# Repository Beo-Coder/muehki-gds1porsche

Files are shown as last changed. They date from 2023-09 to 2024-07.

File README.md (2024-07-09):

# Porsche Mü(h)k

### Raspberry Pi Pico powered HID joystick for an old Porsche tractor

# Table of Contents
1. [Features](#features)
2. [Description](#description)
3. [Pinout](#pinout)
4. [Settings](#settings)
   1. [Load Preset](#load-preset)
   2. [Save Preset](#save-preset)
   3. [Modify Preset](#modify-preset)
      1. [General Settings](#general-settings)
      2. [Axes Settings](#axes-settings)
      3. [Button Settings](#button-settings)
  
   4. [Reinit Joystick](#reinit-joystick)
   5. [Reset Preset](#reset-preset)
   6. [Factory Reset](#factory-reset)
   7. [Disable Output](#disable-output)
5. [Notes](#notes)

# Features

- upto 8 analog axes
- upto 24 digital buttons
- fully customizable axes control curves
- fully customizable button behavior
- 10 different config presets
- easy control over rotary controller and LCD
- acts as gamepad or keyboard
- expandable 

# Description

Porsche Mü(h)k is a Raspberry Pi Pico powered controller
to emulate a HI-Device to control various games by using real actuators such as steering wheel,
gas and break pedal of a real tractor/car.
Various actuators can be connected either as analog or digital sensors, like potentiometers and buttons.
It can emulate a gamepad/joystick or a keyboard, depending on which mode is desired.
Each analog axis can operate in one of four different modes, giving full control over the behavior of the axis.

**It may be useful to use an emulator on the host PC to further configure the axes and buttons.**
# Usage

1. Connect all analog and digital actuators according to the pinout guide
2. Connect the Pico to a computer/laptop
3. Load/modify a preset
4. Have fun!

# Pinout
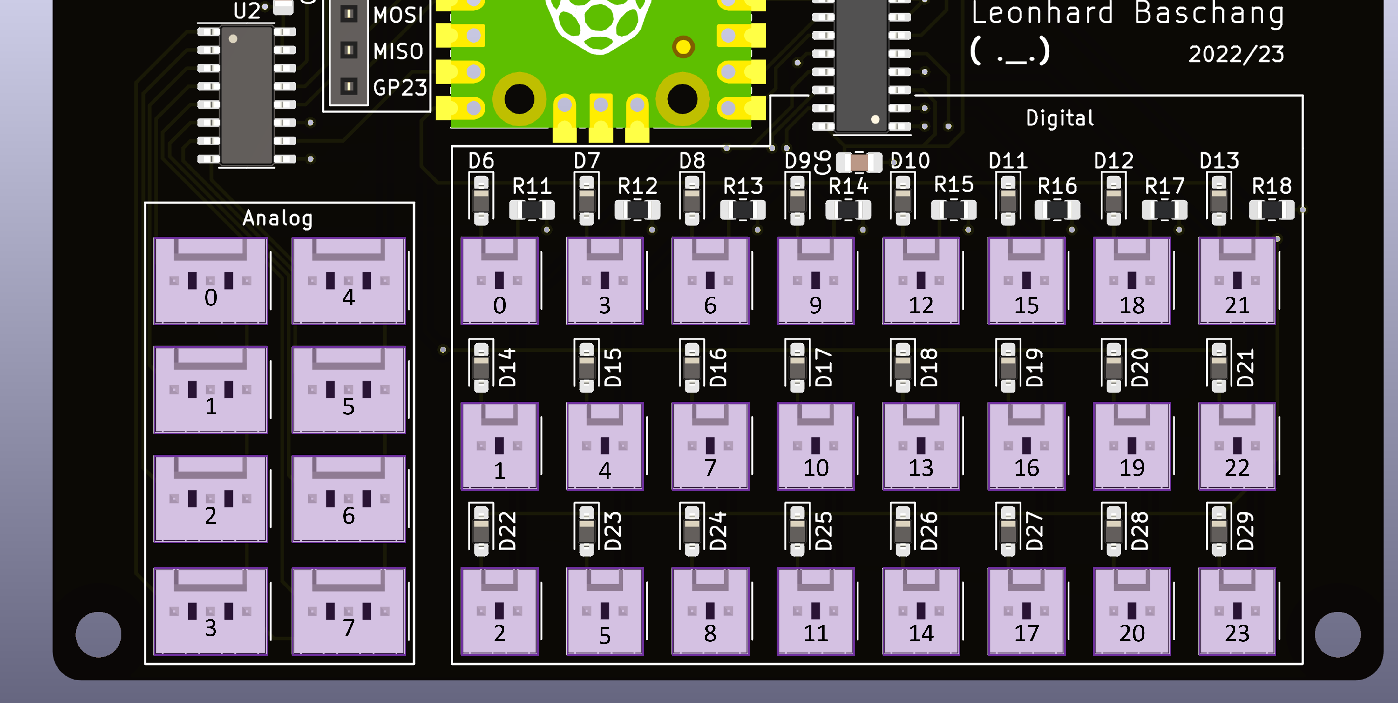
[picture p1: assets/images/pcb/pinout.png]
pinout


**Note**  
0 = Axis/Button 0 in software.  
If an axis/button is connected to port 2, but in software only two axes/buttons are selected,
the input is not sampled and has no output.

### Analog Headers

<pre> 
            +-----------+
+-----------+-----------+-----------+
|           |           |           |
|     A     |    GND    |    Vcc    |
|           |           |           |
+-----------+-----------+-----------+
</pre>

- A = Analog Input  
- GND = GND
- Vcc = Vcc (3.3V)  

### Digital Headers
<pre>
      +-----------+
+-----------+-----------+
|           |           |
|     S1    |    S2     |
|           |           |
+-----------+-----------+
</pre>

- S1 = Button contact 1
- S2 = Button contact 2

The Button must close or open these two connections.

**More detailed pinout in hardwareReadme**

# Settings

## Load Preset

1. Go to /Settings/Set Preset
2. Select desired preset
3. The Device will reset automatically

## Save Preset

1. Go to /Settings/Save Preset
2. Select desired preset
3. The config is saved to the preset

## Modify Preset

### General Settings
Menu: /Settings/General

- Number of Axes: Select the number of analog inputs/axes (0–8).
- Number of Buttons: Select the number of digital inputs/buttons (0–24).
- Digital Axis Mode: Set the mode for all axes
  - Analog: Axes will be emulated as analog axes (joystick)
  - Analog/Digital: Axes will be emulated as buttons on a joystick (only digital axes)
  - Keyboard: Axes and buttons will be emulated as a keyboard

On Analog/Digital and Keyboard mode, each axis will get two buttons/digital outputs assigned. 
One for an upper limit, one for a lower limit.
In these modes, an axis has only three states: center/off, upper limit, lower limit.

**Important:** After any change of these settings, you have to save the preset and restart the device! [Save Settings](#save-preset), [Reinit Joystick](#reinit-joystick)

### Axes Settings
Menu: /Settings/Axes/{*number of axis*}

- Calibrate: Calibrates the axis
- Base set: Sets the base of the control curve (only in exponential and logarithmic mode)
- Mode: Sets the mode of the axis (linear, exponential, logarithmic, digital)
- Digital Calibration: Calibration for digital mode

#### Calibration
It will calibrate your axis settings.  
Set the minimum position of the axis, this is the position where the output of the axis is the smallest.
Same with the maximum.  
If the center position is not calibrated, the center position is automatically set to the midpoint between minimum and maximum.
If the center is calibrated, one half of the calibration curve can be shorter/longer than the other.

#### Modes
- linear: The curve of the output is linear to the input
- exponential/logarithmic: The curve of the output is exponential/logarithmic to the input (based on base)
- digital: The axis has three states (center/off, upper limit, lower limit) in the general "Analog" mode these will be represented as an analog axis which is either 0, maximum or minimum.

#### Base set
In exponential and logarithmic mode, the base will set the curvature/steepness of the output curve.  
The output curve is split in two halves (base 0 and base 1).
Each base can be set separately, or both bases can be set to the same value.  
Base 0 is the base for the curve between minimum and the center, base 1 for the middle between maximum.  
For exponential curves the value should be greater than 0, for logarithmic curves the value should be smaller than 0.  
If the value is 0, it is linear.  
See also the diagrams below.

#### Digital Calibration
This will select the digital lower and upper limit of the axis.  
Set the position after which the lower/upper output/button should be pressed/set to minimum/maximum.  
All input values that are smaller/greater than the limit will result in the minimum/maximum output value.  
If the input value is between the boarder, no button is pressed (in (general) Analog/Digital or Keyboard mode) or the axis will be 0/center position ((general) Analog Mode).

#### Diagrams
The x-axis represents the input value.
- 0 = center (input) position
- -10 = minimum (input) position
- 10 = maximum (input) position

All of these values can be calibrated with axis calibration.

The y-axis represents the output value (analog mode only)
- 0 = center/0 output
- -10 = minimum (output) value
- 10 = maximum (output) value

Base 0 is the base for the curve between minimum and the center, base 1 for the middle between maximum.

These values will can't be directly controlled.

##### Linear curves:

| Linear axis curve without center calibration | Linear axis curve with (different) center calibration | Linear axis curve with (different) center calibration, different minimum calibration |
|---|---|---|
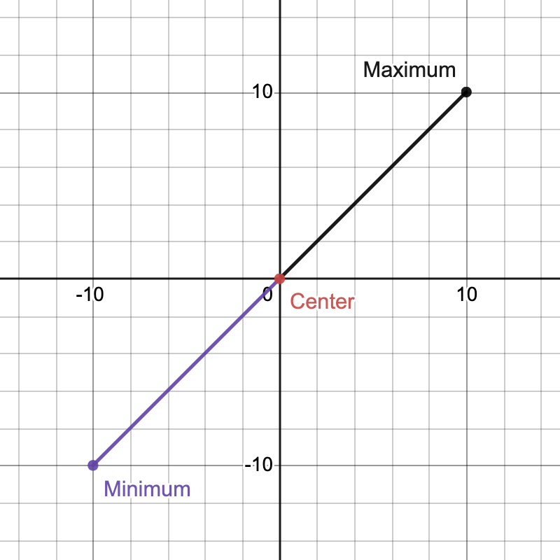
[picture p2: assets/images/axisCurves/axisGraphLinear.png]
linear diagram no center calibration linear axis control curve
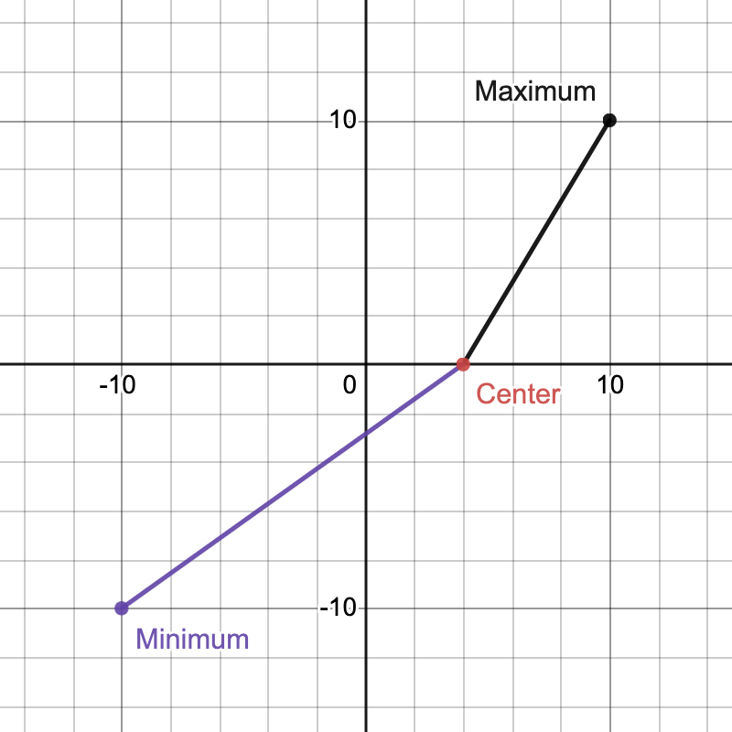
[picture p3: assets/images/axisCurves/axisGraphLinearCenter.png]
linear diagram center calibration linear axis control curve
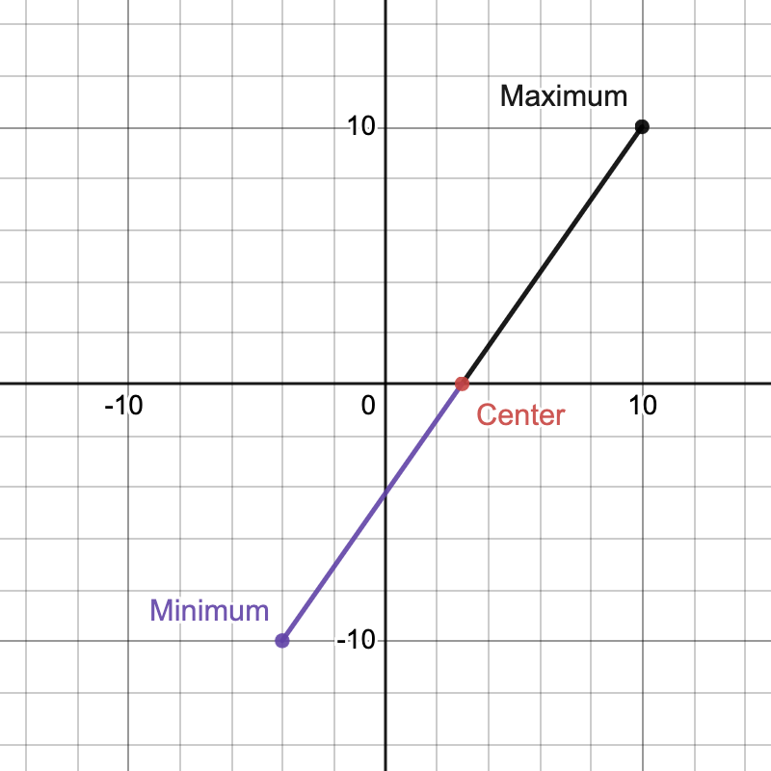
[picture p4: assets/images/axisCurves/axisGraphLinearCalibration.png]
linear diagram center calibration linear axis control curve
|  |  |  |

##### Exponential curves:
| Exponential axis curve without center calibration, same bases | Exponential axis curve without center calibration, different bases | Exponential axis curve with (different) center calibration, different bases |
|---|---|---|
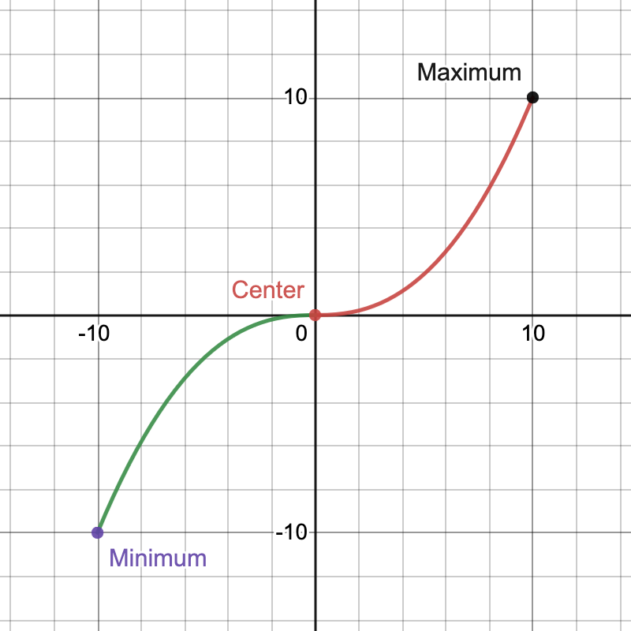
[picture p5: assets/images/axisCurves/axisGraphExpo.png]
expo diagram same bases no center calibration expo axis control curve
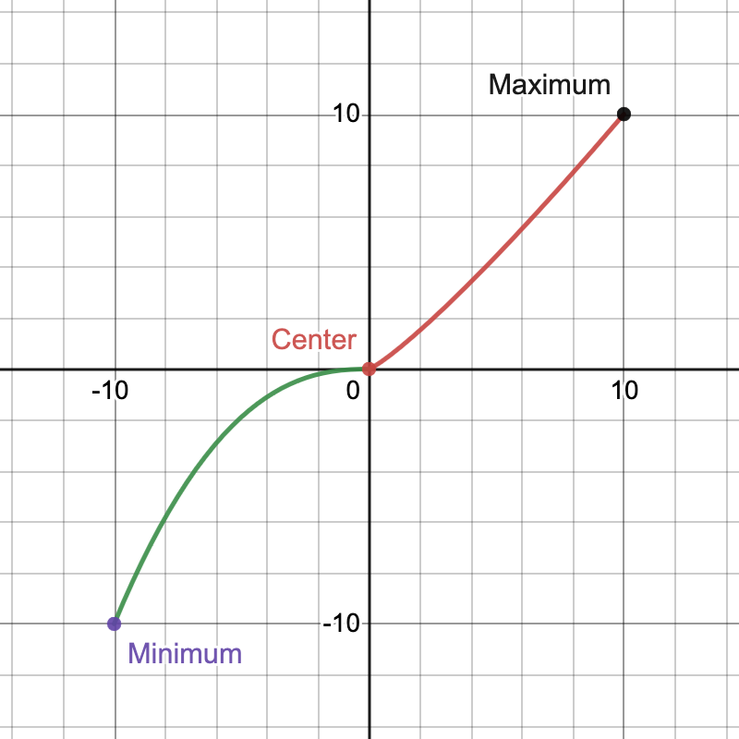
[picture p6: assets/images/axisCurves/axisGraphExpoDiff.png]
expo diagram diff base no center calibration expo axis control curve
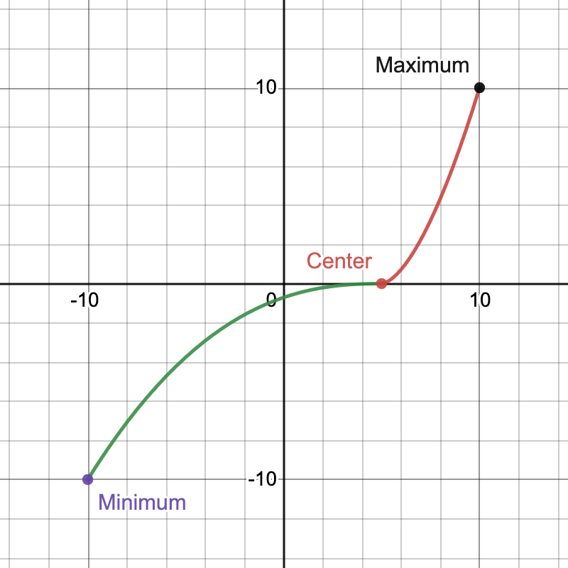
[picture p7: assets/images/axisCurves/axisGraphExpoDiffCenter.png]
expo diagram diff bases center calibration expo axis control curve
|  |  |  |

##### Logarithmic curves:
| Logarithmic axis curve without center calibration, same bases | Logarithmic axis curve without center calibration, different bases | Logarithmic axis curve with (different) center calibration, different bases |
|---|---|---|
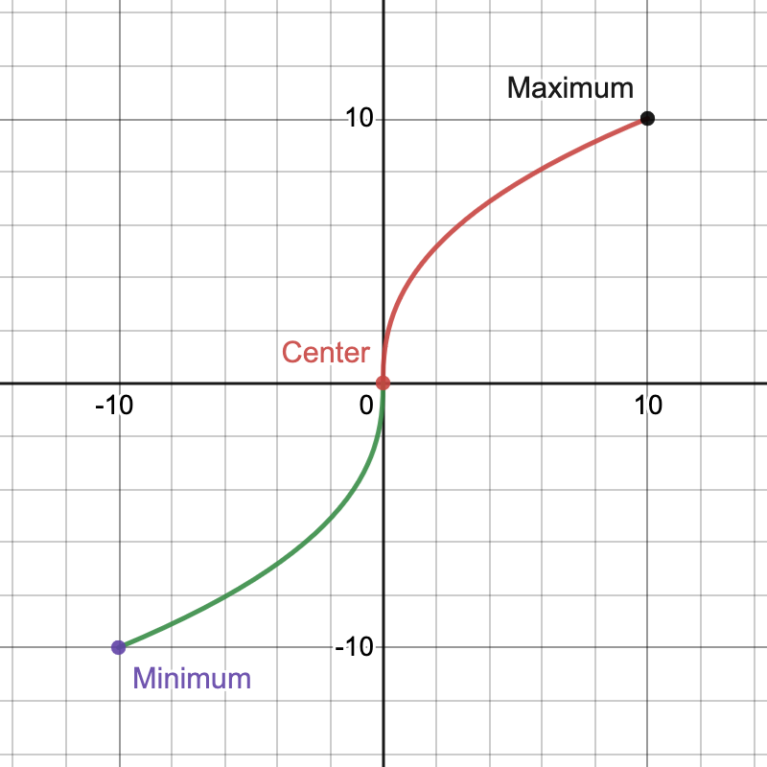
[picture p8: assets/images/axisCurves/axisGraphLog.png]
log diagram same bases no center calibration log axis control curve
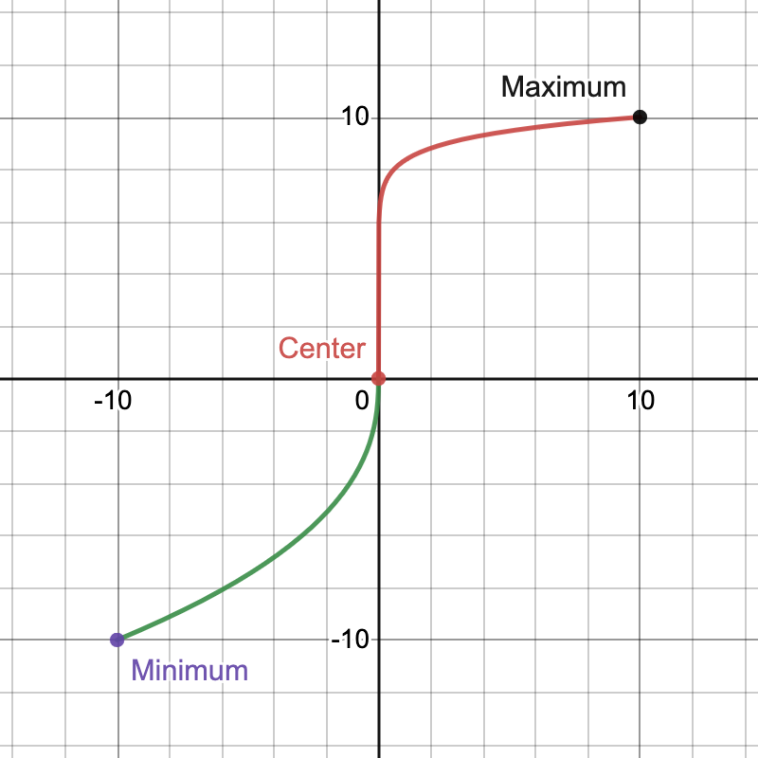
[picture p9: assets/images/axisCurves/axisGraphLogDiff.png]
log diagram diff base no center calibration log axis control curve
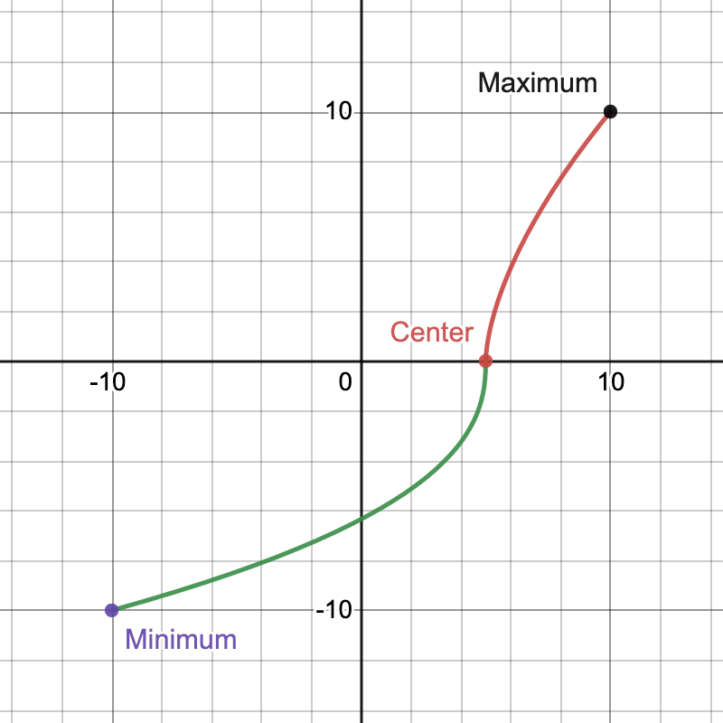
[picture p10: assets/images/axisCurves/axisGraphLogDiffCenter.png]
log diagram diff bases center calibration log axis control curve
|  |  |  |

##### Other curves (Combinations of all) :
| Exponential half with other half linear (without center calibration) | Exponential half with other half linear, (different) center calibration | Logarithmic half with other half exponential, (different) center calibration |
|---|---|---|
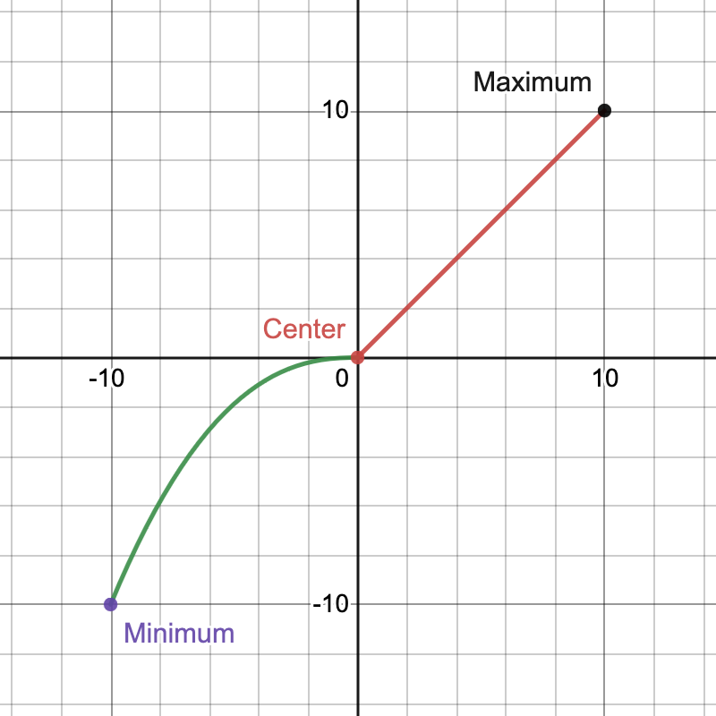
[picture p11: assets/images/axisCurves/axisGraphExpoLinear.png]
Exponential half with other half linear (without center calibration) other axis control curve
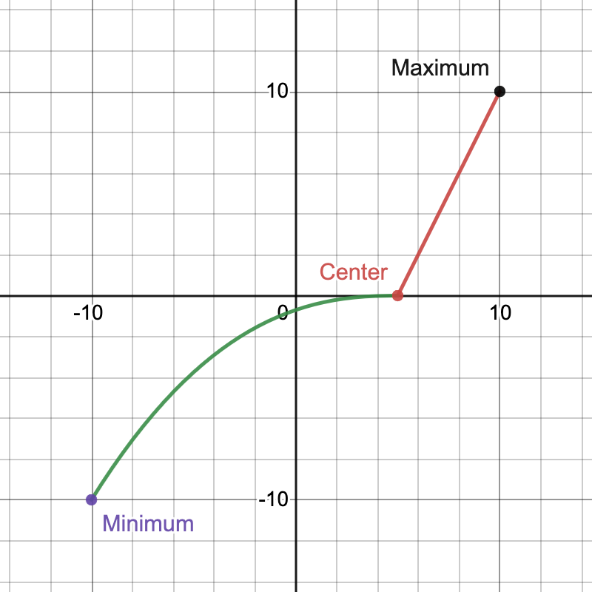
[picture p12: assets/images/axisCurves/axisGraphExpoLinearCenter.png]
Exponential half with other half linear, (different) center calibration other axis control curve
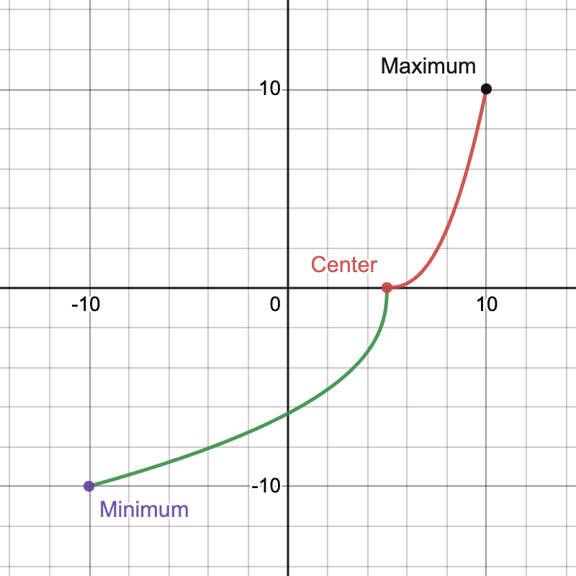
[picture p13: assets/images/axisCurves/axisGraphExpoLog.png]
Logarithmic half with Exponential other, (different) center calibration other axis control curve
|  |  |  |

**Note:**
There are many other ways to adjust the curves. See also the Desmos calculator: [Desmos calculator](https://www.desmos.com/calculator/y6jawpiyea)  
Note that the values of the Desmos calculator do not match those of the device.

### Button Settings

Menu: /Settings/Buttons/{*number of button*}

- Mode: Whether the button should behave as (temporary) button or as (toggle) button
- Type: Whether the button is NO (normally open) or NC (normally closed)

#### Mode
- Button: Button behaves as a button. There is only an output when the button is pressed.
- Toggle: Button behaves as a toggle button. Ont the first press the output goes high/1, the next press sets the output to 0/low.

#### Type
- Normally Open
- Normally Closed

Whether the button opens or closes on a press.

**Important:**
Axes and button settings are adapted immediately.
To keep them after the joystick is reloaded or turned off the settings must be saved. [Save Settings](#save-preset)  
There is no need to reinit the joystick after axes or button settings have changed.

## Reinit Joystick

This option reloads the joystick. 
All settings that are not saved will be lost.

## Reset Preset

The current selected preset will be set to factory settings.
After that, the joystick will be reloaded.

## Factory Reset

All settings (all presets) are set back to factory settings.
After that, the joystick will be reloaded.

## Disable Output
This setting disables the output of the computer.  
Especially useful in Keyboard mode.  
Press it again to enable the output again.

# Notes
The configuration/device can be tested on gamepad/joystick test websites/software.  
Example website I used for testing: [Gamepad tester](https://hardwaretester.com/gamepad)

More detailed hardware/software guides are under [READMEhardware](READMEhardware.md)/[READMEsoftware](READMEsoftware.md)  
There are also the board dimensions as well as the schematic/gerber files.

There are no settings stored on the Pico. So the Pico can also be used for other projects.

If there are any bugs/problems, or you have any questions, please contact me.

Mühk or Mük is are the same things. :)

( ._.)

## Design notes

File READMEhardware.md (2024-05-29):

# Porsche Mü(h)k Hardware

# Table of Contents
1. [Intro](#intro)
2. [Overview](#overview)
3. [Parts](#parts)
4. [Pinout](#pinout)
5. [Schematic](#schematic)
6. [Dimensions](#dimensions)

# Intro
This Readme file focuses on the hardware of Porsche Mü(h)k.

# Overview
The main part is the Raspberry Pi Pico MCU.
All the configuration data is stored on an external (64 Kb) EEPROM, so that the MCU can be exchanged and used for other projects.  
An 8-channel 12-bit ADC is used to interface up to eight analog sensors.  
An 8:1 analog multiplexer is used to further reduce the used pins of the Pico for up to 24 digital inputs.  
The board has connections for a rotary encoder (with button) and an I2C LCD.  
The board also has an area and connections to add an extra shield that can add various functions.  
All buses (SPI, I2C, UART) are routed out for easy debugging and/or add-ons/modifications.  
It has two LEDs for debug purposes.  
There is a 8x3 button matrix, with n-key rollover.
So each combination of buttons can be pressed and there is no ghosting.

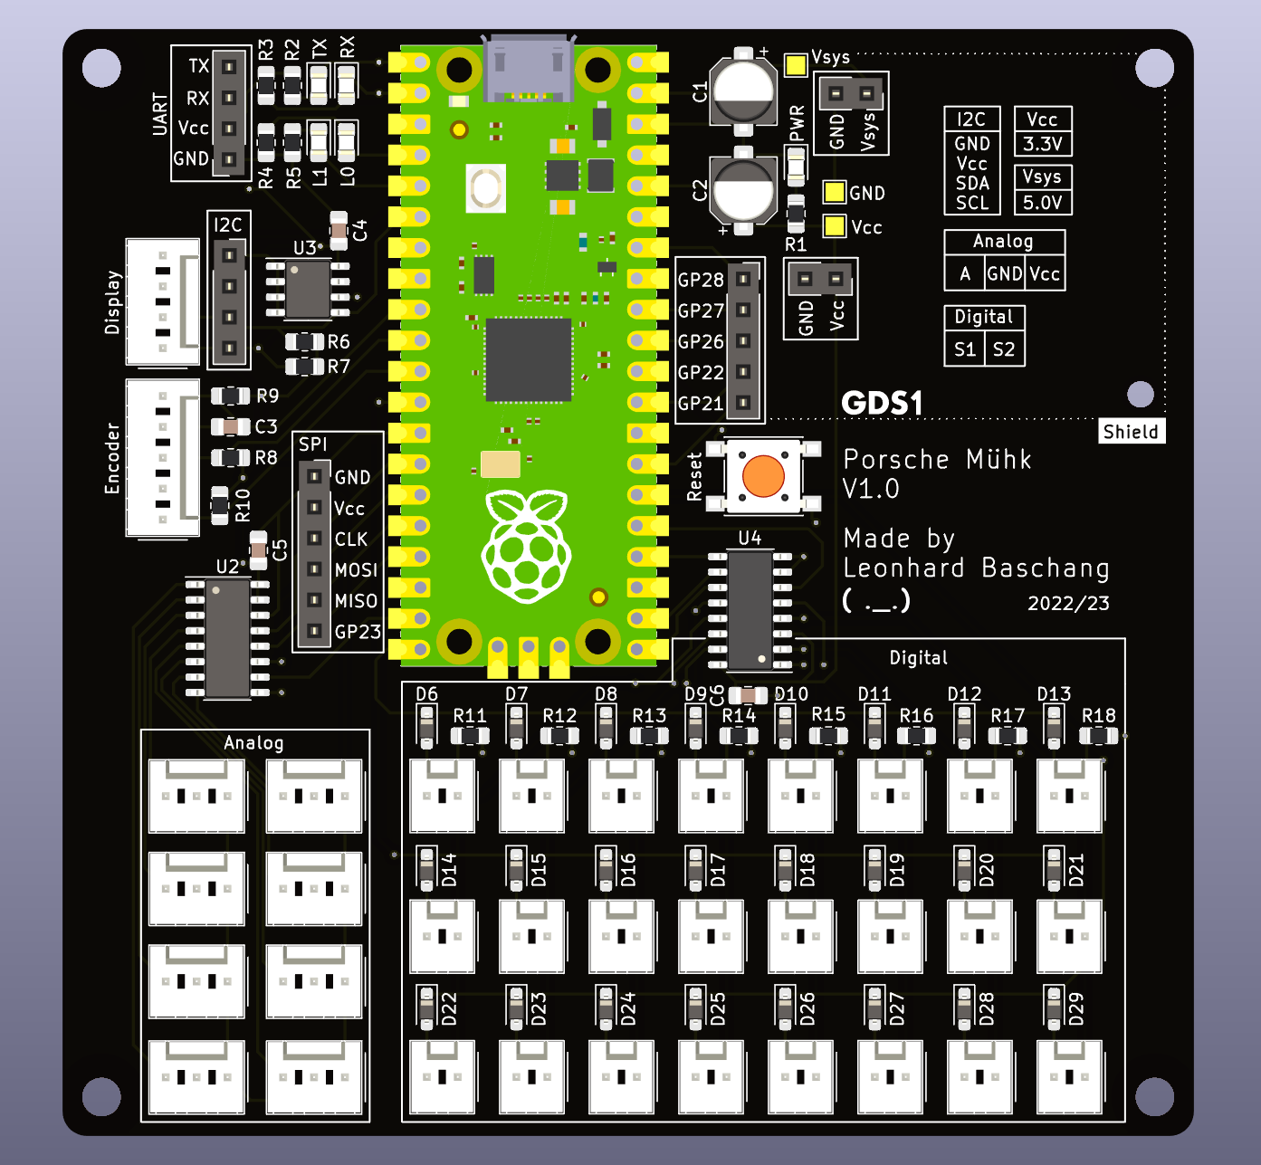
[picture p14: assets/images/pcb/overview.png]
overview


# Parts
- U1: Raspberry Pi Pico ([Raspberry Pi Pico](https://www.raspberrypi.com/products/raspberry-pi-pico/))
- U2: 8-Channel 12-Bit SPI ADC ([Microchip MCP3208](https://www.microchip.com/en-us/product/MCP3208))
- U3: 64 Kb I2C EEPROM ([Microchip 24LC64](https://www.microchip.com/en-us/product/24LC64))
- U4: 8:1 MUX ([Microchip CD74HC4051](https://www.ti.com/product/CD74HC4051))

- Display: Basic 20x4 I2C LC-Display (e.g. [LCD 20x4 AZ-Delivery](https://www.az-delivery.de/en/products/hd44780-2004-lcd-display-bundle-4x20-zeichen-mit-i2c-schnittstelle))
- Rotary Encode: Simple Rotary Encoder with button (e.g. [Rotary Encoder AZ-Delivery](https://www.az-delivery.de/en/products/drehimpulsgeber-modul))

- Connector housings for digital connections [PSK 254/2W](https://www.reichelt.de/kupplungs-leergehaeuse-crimptechnik-2-polig-psk-254-2w-p14857.html)
- Connector housings for analog connections [PSK 254/3W](https://www.reichelt.de/kupplungs-leergehaeuse-crimptechnik-3-polig-psk-254-3w-p14858.html)
- Connector housings for display connection [PSK 254/4W](https://www.reichelt.de/kupplungs-leergehaeuse-crimptechnik-4-polig-psk-254-4w-p694.html)
- Connector housings for encoder connection [PSK 254/5W](https://www.reichelt.de/kupplungs-leergehaeuse-crimptechnik-5-polig-psk-254-5w-p14859.html)
- Crimp contact for the housing [PSK-Contacts](https://www.reichelt.de/crimpkontakte-fuer-psk-254--20-stueck-psk-kontakte-p14861.html)

# Pinout

pinout

**Note**  
0 = Axis/Button 0 in software.  
If an axis/button is connected to port 2,
but in software only two axes/buttons are selected, the input is not sampled and no output.

### Analog Headers

<pre> 
            +-----------+
+-----------+-----------+-----------+
|           |           |           |
|     A     |    GND    |    Vcc    |
|           |           |           |
+-----------+-----------+-----------+
</pre>
- A = Analog Input
- GND = GND
- Vcc = Vcc (3.3V)

Analog input should not exceed Vcc (3.3V)

### Digital Headers
<pre>
      +-----------+
+-----------+-----------+
|           |           |
|     S1    |    S2     |
|           |           |
+-----------+-----------+
</pre>

- S1 = Button contact 1
- S2 = Button contact 2

The Button must close or open these two connections.

### Display Header
<pre> 
            +-----------------------+
+-----------+-----------+-----------+-----------+
|           |           |           |           |
|    GND    |    +5V    |    SDA    |    SCL    |
|           |           |           |           |
+-----------+-----------+-----------+-----------+
</pre>
- GND = GND
- +5V = +5V
- SDA = SDA (GPIO 4)
- SCL = SCL (GPIO 5)

SDA and SCL have a logic level of Vcc (3.3V)

### Encoder Header
<pre>
            +-----------------------------------+
+-----------+-----------+-----------+-----------+-----------+
|           |           |           |           |           |
|    CLK    |    GND    |    DT     |    GND    |    BT     |
|           |           |           |           |           |
+-----------+-----------+-----------+-----------+-----------+
</pre>
- CLK = CLK-Pin of Encoder
- GND = GND
- DT = DT-Pin of Encoder
- BT = Button pin of Encoder

CLK, DT and BT are pulled up to VCC. To get a signal, they need to be connected to GND.

**Note**  
During testing, I found a problem with presumably voltage spikes from the encoder when it is turned. 
To reduce them put a ceramic capacitor in parallel with a resistor in series with the CLK signal. 
This should be as close to the encoder as possible.
In a next version of the pcb, this maybe could be put on the pcb itself.
<pre>
                                 +------------+  
                           +-----+            +-----+
                           |     +------------+     |
                           |          100Ω          |
                           |                        |
CLK from Encoder +---------+                        +---------+ CLK to CLK Pin on Header
                           |                        |
                           |         |    |         |
                           |         |    |         |
                           +---------+    +---------+
                                     |    | 
                                     |    | 
                                      100nF
</pre>
### Notes
Note that all pins are only 3.3V tolerant.  
The various other connectors (SPI, I2C, UART, GPIO) are labeled on the silkscreen of the PCB.
CS of the ADC is on GPIO 14.  
LED 0 (L0) is connected to GPIO 2.  
LED 1 (L1) is connected to GPIO 3.

# Schematic
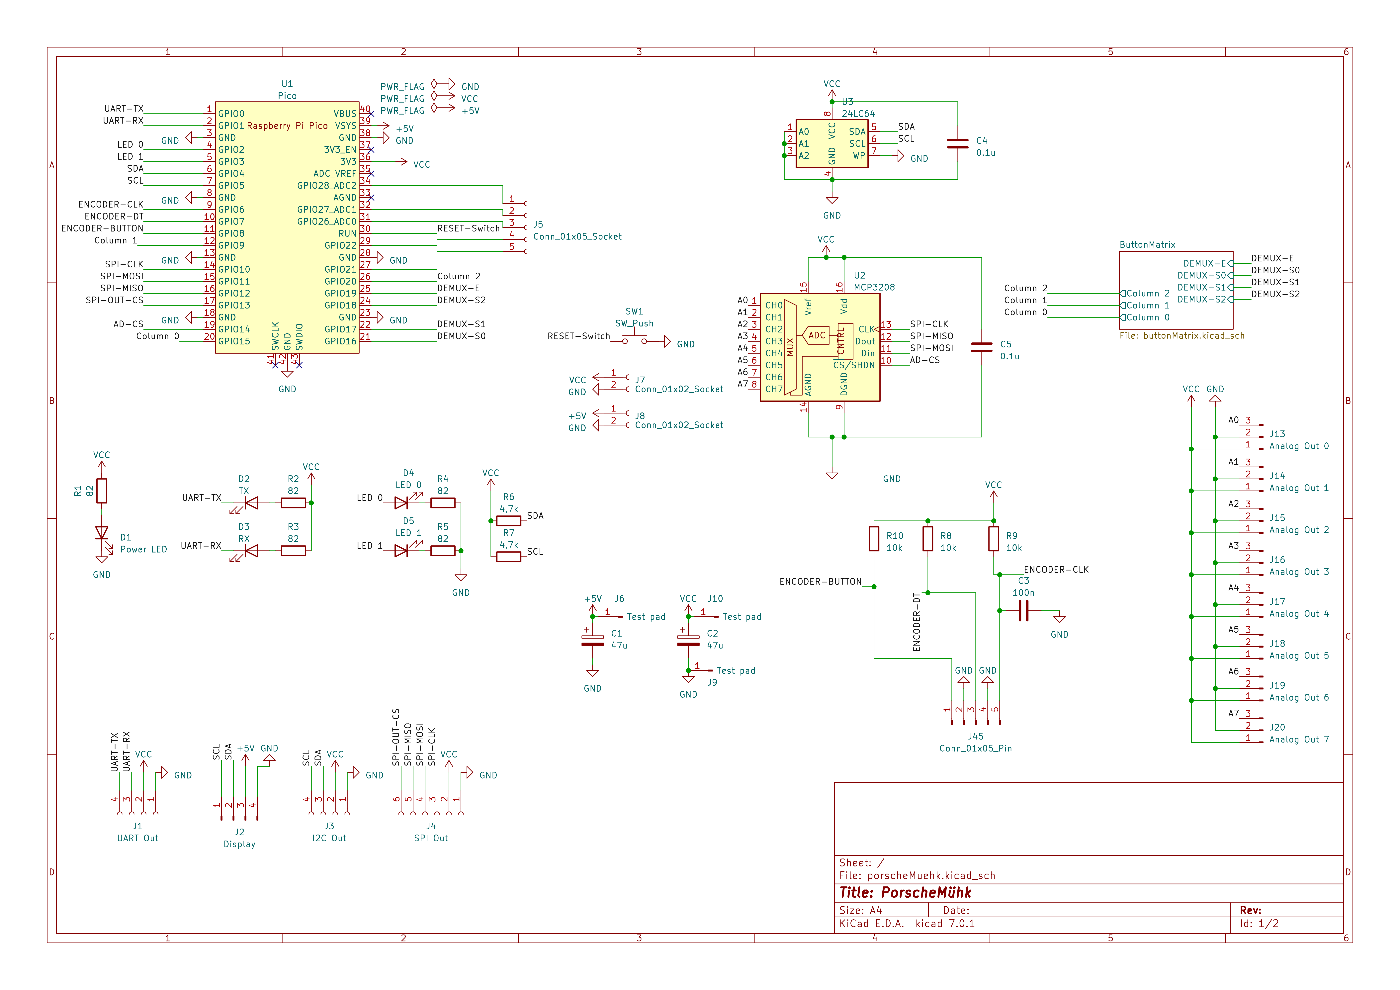
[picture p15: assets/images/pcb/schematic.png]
schematic


## Button matrix schematic
schematic button matrix

# Dimensions

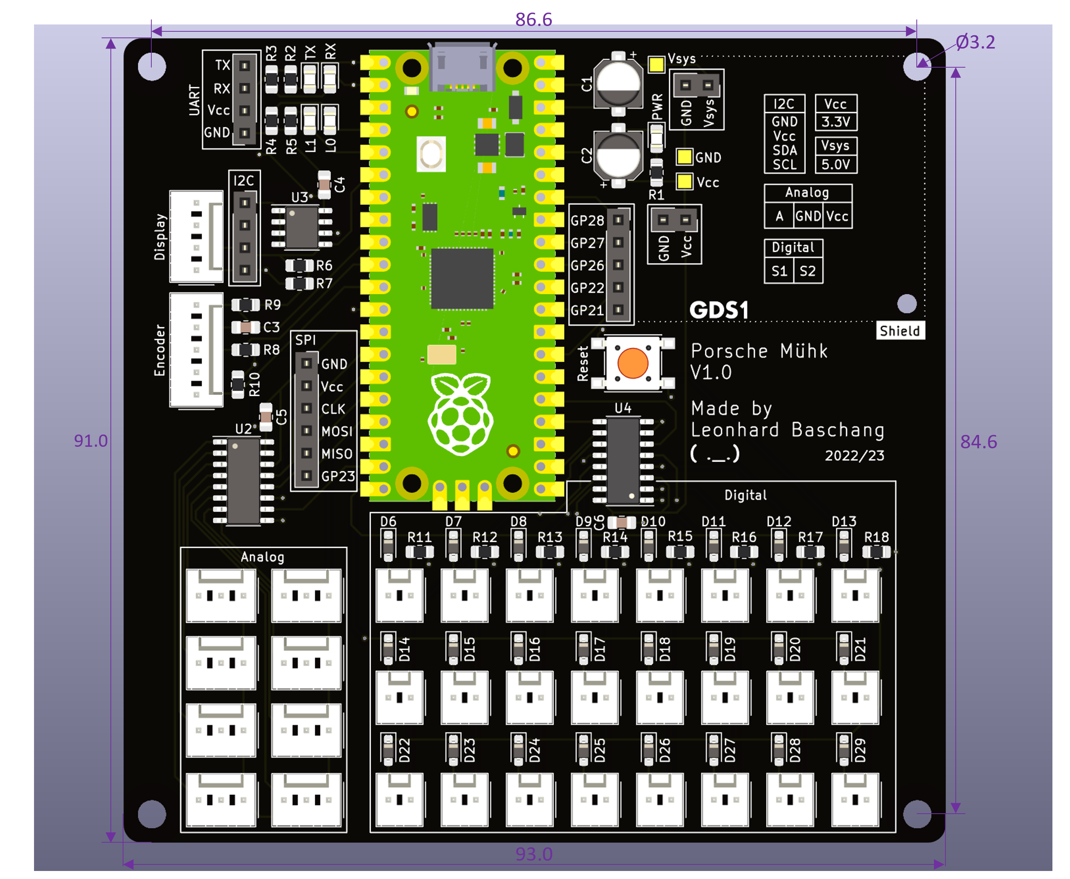
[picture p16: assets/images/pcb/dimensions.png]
dimensions


## Shield Dimensions

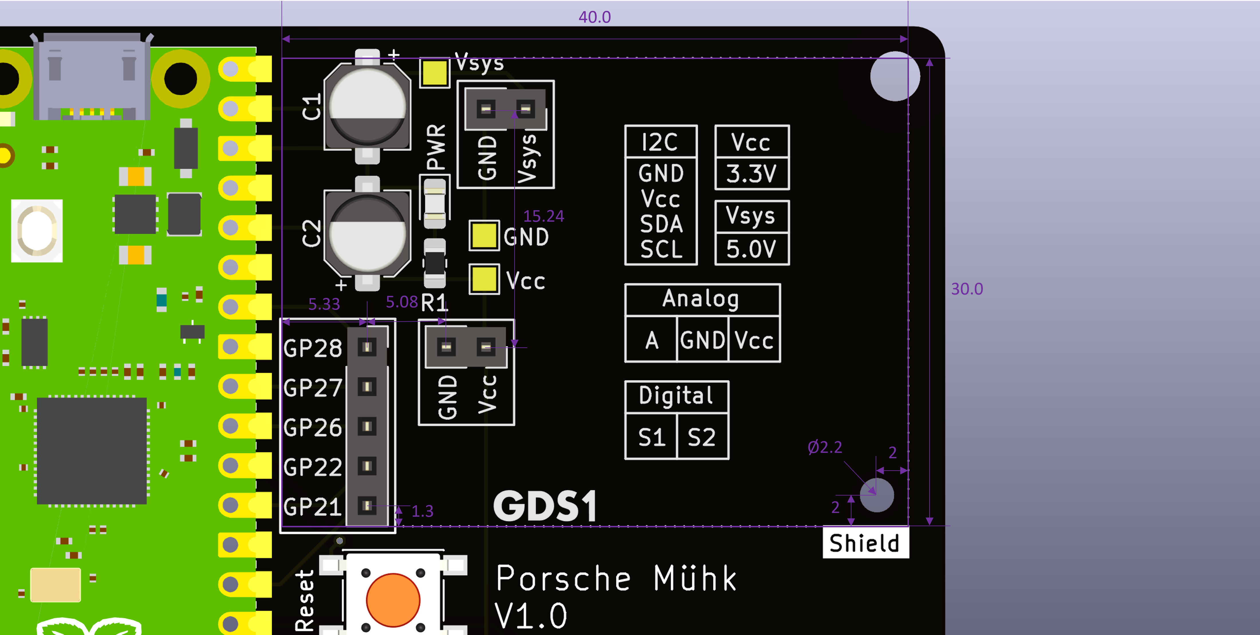
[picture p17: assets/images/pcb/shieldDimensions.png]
shield dimensions dimensions shield


## Notes
All the connectors for the shield are spaced with multiple of 2.54mm, so normal 2.54mm PCB can be used.  
All dimensions in mm.
KiCAD files and gerber files can be found [here](hardware)

( ._.)

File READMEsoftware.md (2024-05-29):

# Porsche Mü(h)k Software

# Table of Contents
1. [Intro](#intro)
2. [Overview](#overview)
3. [Emulating](#emulating-a-gamepadkeyboard)
4. [Memory Map](#eeprom-memory-map)

# Intro
This Readme file focuses on the software of Porsche Mü(h)k.

# Overview
This file will not explain all aspects of the software.
Only important principles are explained.  

The software is written in C/C++ with Platform IO.
It can also be imported in the Arduino IDE.

I know that the software can certainly be made better and cleaner.
Especially the whole menu LCD input.

# Emulating a Gamepad/Keyboard

In Analog and Analog/Digital mode the Pico will emulate a gamepad.

Each axis on the device will be one axis on the gamepad.
Each button on the device will be one button on the gamepad.  
In Analog/Digital mode for each axis, there are two extra buttons created.

To know which axis/button is which uses a gamepad tester.
Example website I used for testing: [Gamepad tester](https://hardwaretester.com/gamepad)

For the Keyboard mode, each button has one key and each axis has two keys.  
The emulated Keyboard is an n-key rollover keyboard.  
To know which axis/button is which use a keyboard tester.
Example website I used for testing: [Keyboard tester](https://keyboard-test.space/)

The libraries used for emulating were written by me  
[Gamepad library](https://github.com/Beo-Coder/muehk-lib-JoystickHID)  
[Keyboard library]() - Coming soon (or never... (Just see the code if you need it))

# EEPROM Memory Map

All configuration data is stored on the external EEPROM chip.
The EEPROM I used has an address range from 0x0000 to 0x1FFF so 8191 bytes in total.

The EEPROM is divided into two different sections. 
A general section and the sections for all presets.

The general section is 20 bytes wide and stores the following:
- current preset
- 19 unused bytes

General section memory map:
<pre>
0x0000:  +-----------------------------------+
         | Current preset                    |
0x0001:  +-----------------------------------+
         | not used                          |
         .                                   .
         .                                   .
         |                                   |    
0x0014:  +-----------------------------------+
         |                                   |
         .                                   .
</pre>

The preset section contains all presets.
A preset is 405 bytes wide. So the reset of the EEPROM could theoretically store up to 20 presets.  

A preset contains the following data:
- 32 bytes per axis (2 bytes per calibration data, 2 bytes per digital calibration, 8 bytes per base, 1 byte for the mode, 1 byte for 8 single bit data, 4 bytes not used)
- 2 bytes per button (1 byte for 8 single bit data, 1 byte not used)
- 5 bytes for a general section (1 byte for axis count, 1 byte for button count, 1 byte for the joystick mode, 2 bytes not used)

In total, a 405 byte wide preset can hold 10 axes and 40 buttons.  
With the unused bytes, there is enough space to update/modify smaller things without doing a whole new memory map.  
Because the software normally only stores 10 presets, 4121 bytes are free.
These bytes could be used to store more presets or for any other thing that need to be stored.

Preset memory map:

<pre>
0x0014:  +-----------------------------------+  Preset 0 General Section (5 bytes)
         | Axis count                        |
0x0015:  +-----------------------------------+
         | Button count                      |
0x0016:  +-----------------------------------+
         | Mode                              |
0x0017:  +-----------------------------------+
         | Not used                          |
         |                                   |
0x0019:  +-----------------------------------+  Axis 0 (32 bytes)
         | calibration data 0 MSB            |
0x001A:  +-----------------------------------+
         | calibration data 0 LSB            |
0x001B:  +-----------------------------------+
         | calibration data 1 MSB            |
0x001C:  +-----------------------------------+
         | calibration data 1 LSB            |
0x001D:  +-----------------------------------+
         | calibration data 2 MSB            |
0x001E:  +-----------------------------------+
         | calibration data 2 LSB            |
0x001F:  +-----------------------------------+
         | digital calibration data 0 MSB    |
0x0020:  +-----------------------------------+
         | digital calibration data 0 LSB    |
0x0021:  +-----------------------------------+
         | digital calibration data 1 MSB    |
0x0022:  +-----------------------------------+
         | digital calibration data 1 LSB    |
0x0023:  +-----------------------------------+
         | base 0                            |
         |                                   |
         |                                   |
         |                                   |
         |                                   |
         |                                   |
         |                                   |
         |                                   |
0x002B:  +-----------------------------------+
         | base 1                            |
         |                                   |
         |                                   |
         |                                   |
         |                                   |
         |                                   |
         |                                   |
         |                                   |
0x0033:  +-----------------------------------+
         | mode                              |
0x0034:  +-----------------------------------+
         | bit data                          |
0x0035:  +-----------------------------------+
         | Not used                          |
         |                                   |
         |                                   |
         |                                   |
0x0039:  +-----------------------------------+  Axis 1-9 (32*9 bytes)
         |                                   |
         .                                   .

         .                                   .
         |                                   |
0x0159:  +-----------------------------------+  Button 0 (2 bytes)
         | single bit data                   |
0x015A:  +-----------------------------------+ 
         | not used                          |
0x015B:  +-----------------------------------+  Button 1-39 (2*39 bytes)
         |                                   |
         .                                   .

         .                                   .
         |                                   |
0x01a9:  +-----------------------------------+  Preset 1 General Section ...
         |                                   |
         .                                   .
         .                                   .
</pre>

To read/write to the EEPROM, I used my own library  
[EEPROM 24 lib](https://github.com/Beo-Coder/muehk-lib-Microchip-EEPROM-24)

( ._.)

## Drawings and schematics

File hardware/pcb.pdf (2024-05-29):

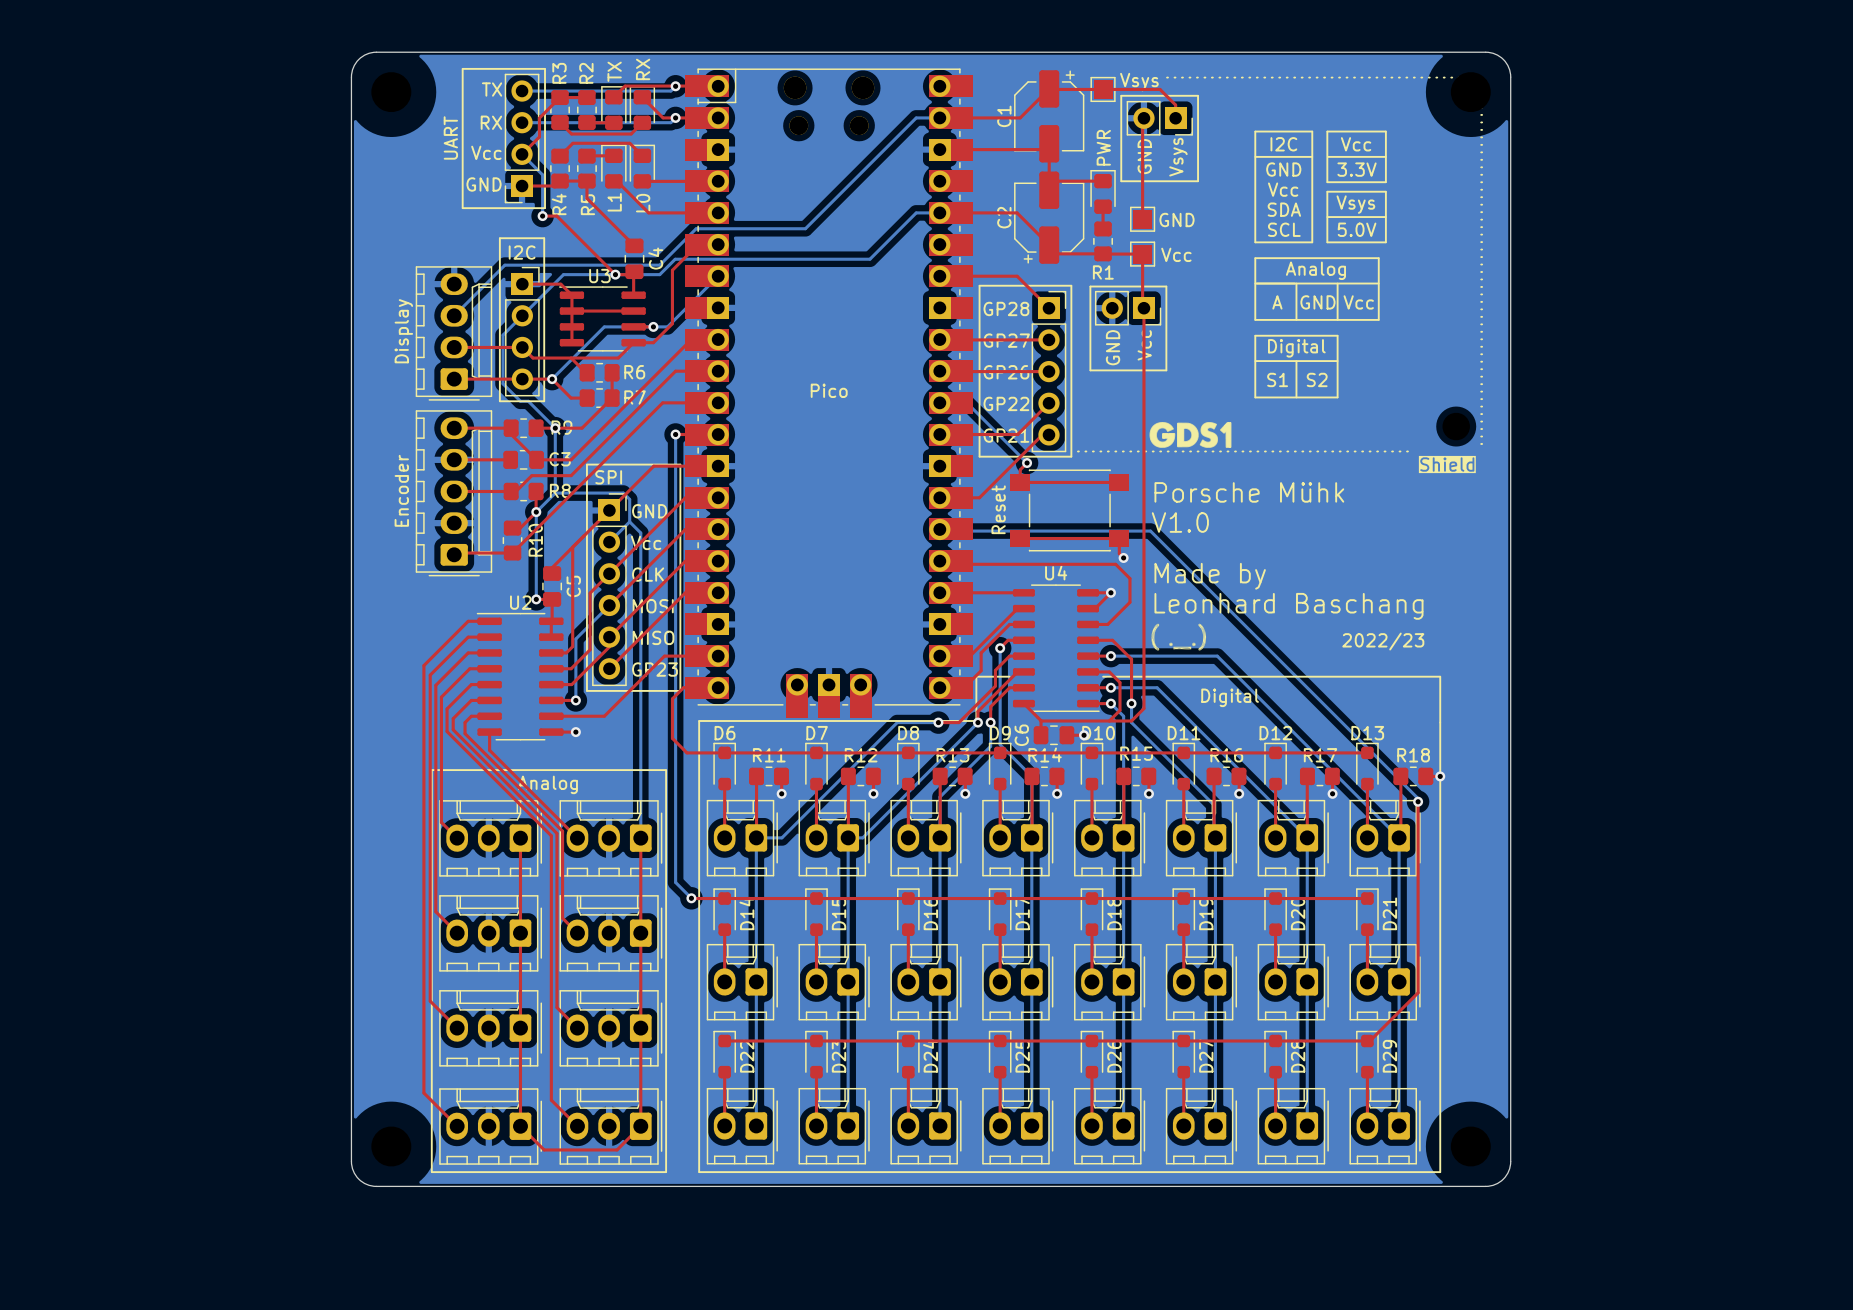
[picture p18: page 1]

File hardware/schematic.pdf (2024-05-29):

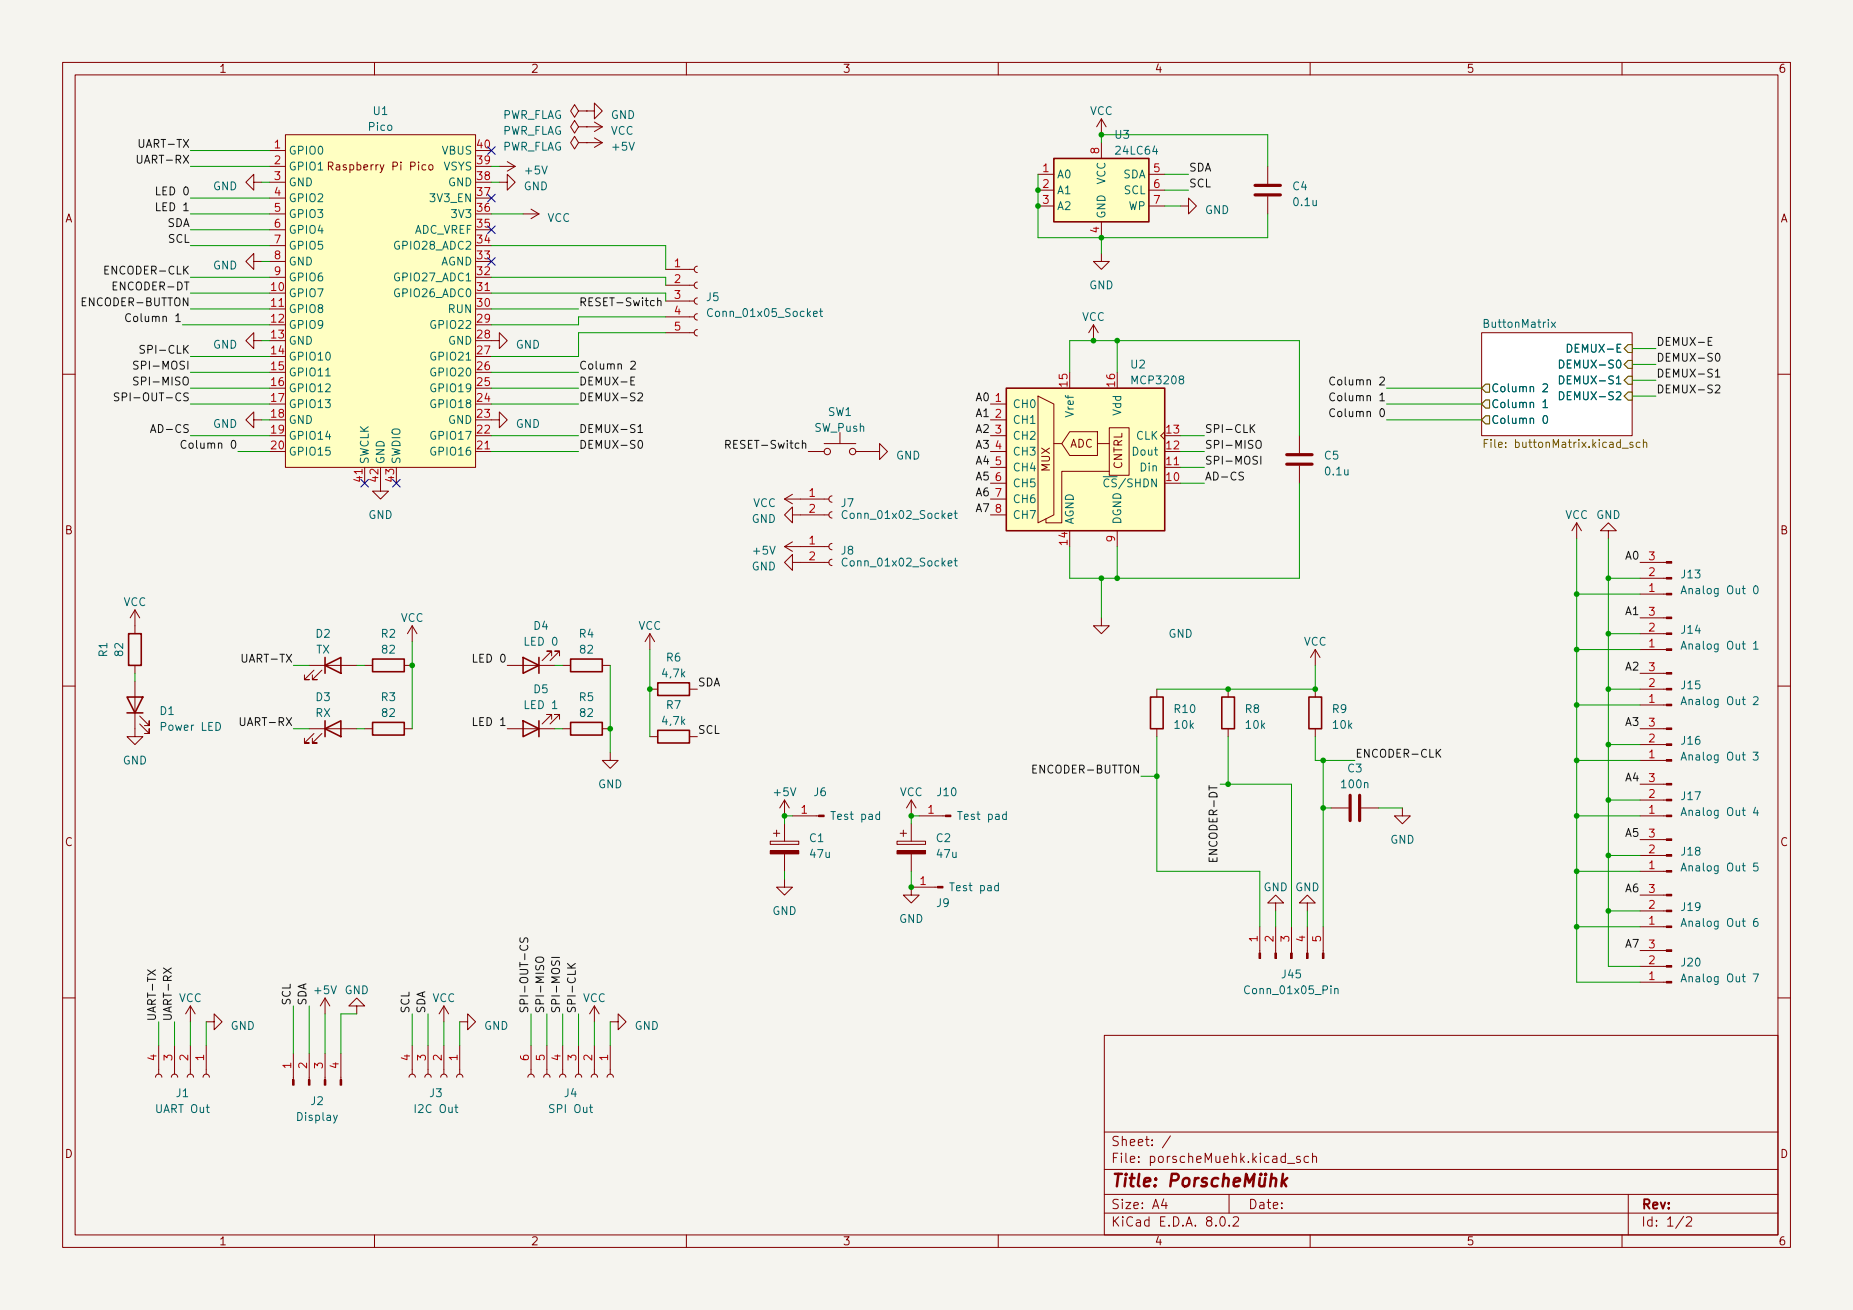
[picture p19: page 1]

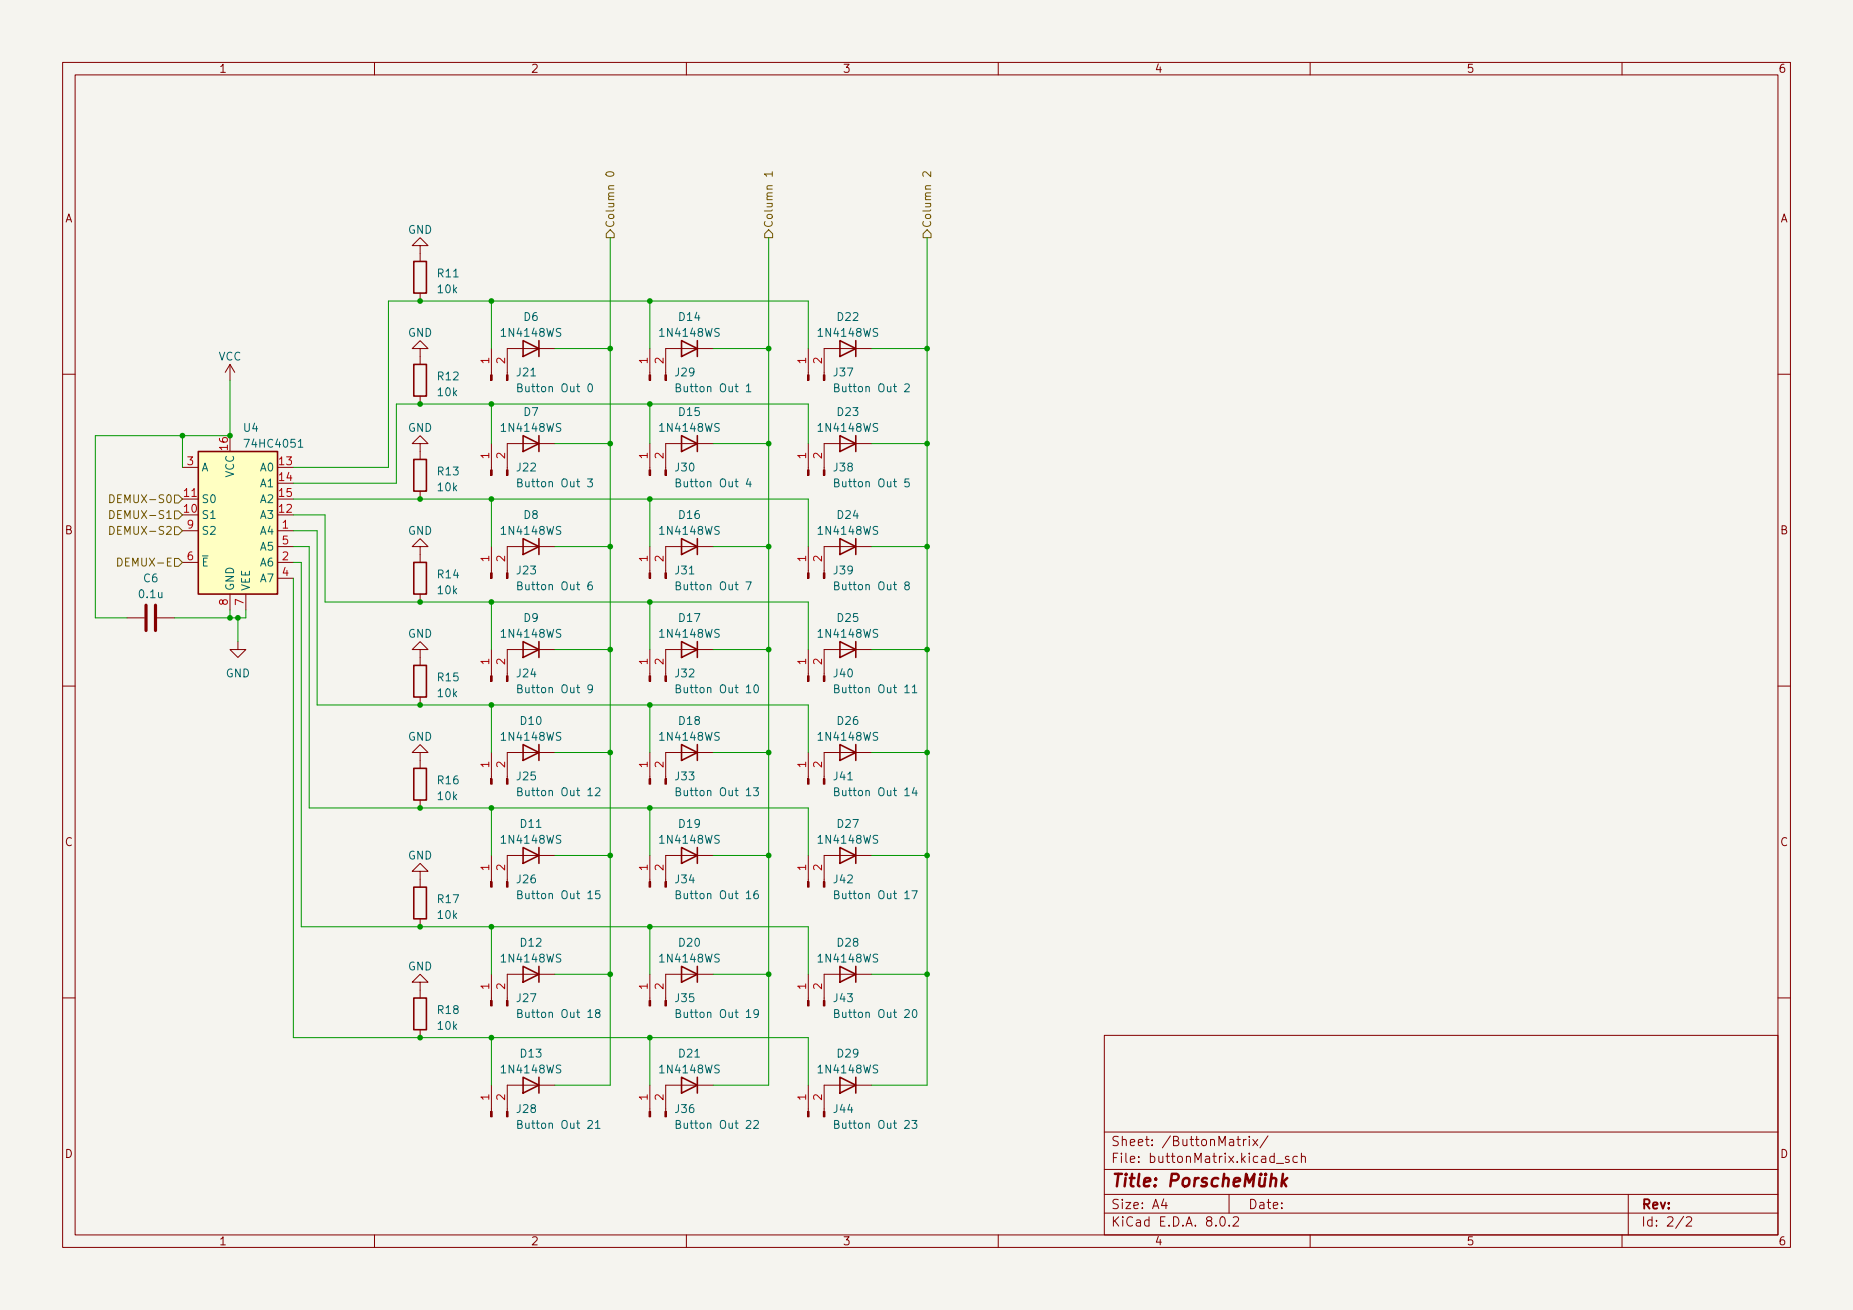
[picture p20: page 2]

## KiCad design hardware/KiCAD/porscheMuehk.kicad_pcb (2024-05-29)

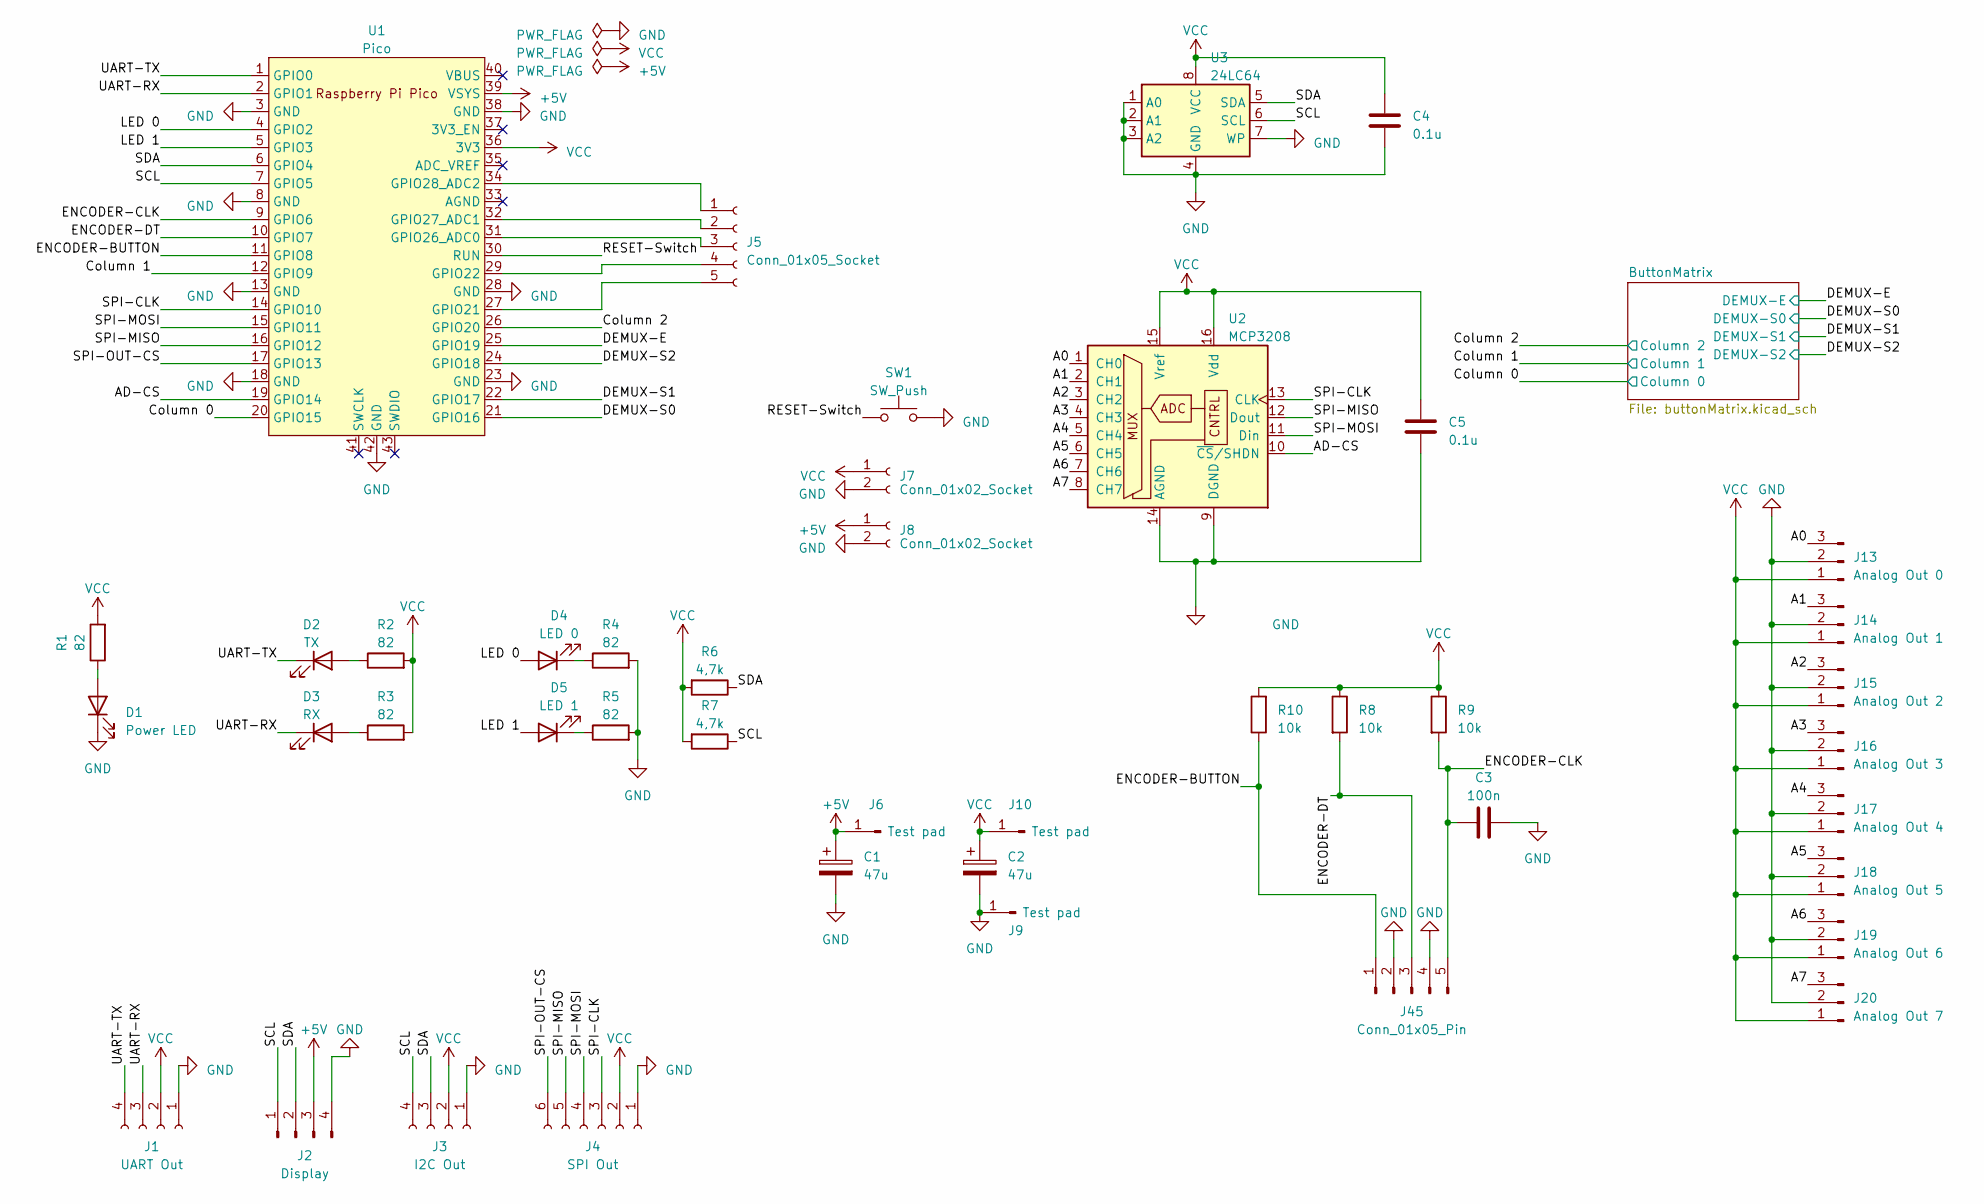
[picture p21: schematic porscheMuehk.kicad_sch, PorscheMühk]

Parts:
C1, C2: 47u; CP_Elec_5x5.3
C3: 100n; C_0805_2012Metric_Pad1.18x1.45mm_HandSolder
C4, C5: 0.1u; C_0805_2012Metric_Pad1.18x1.45mm_HandSolder
D1: Power LED; LED_0805_2012Metric_Pad1.15x1.40mm_HandSolder
D2: TX; LED_0805_2012Metric_Pad1.15x1.40mm_HandSolder
D3: RX; LED_0805_2012Metric_Pad1.15x1.40mm_HandSolder
D4: LED 0; LED_0805_2012Metric_Pad1.15x1.40mm_HandSolder
D5: LED 1; LED_0805_2012Metric_Pad1.15x1.40mm_HandSolder
J1: UART Out; PinSocket_1x04_P2.54mm_Vertical
J2: Display; Molex_KK-254_AE-6410-04A_1x04_P2.54mm_Vertical
J3: I2C Out; PinSocket_1x04_P2.54mm_Vertical
J4: SPI Out; PinSocket_1x06_P2.54mm_Vertical
J5: Conn_01x05_Socket; PinSocket_1x05_P2.54mm_Vertical
J6, J9, J10: Test pad; TestPoint_Pad_1.5x1.5mm
J7, J8: Conn_01x02_Socket; PinSocket_1x02_P2.54mm_Vertical
J13: Analog Out 0; Molex_KK-254_AE-6410-03A_1x03_P2.54mm_Vertical
J14: Analog Out 1; Molex_KK-254_AE-6410-03A_1x03_P2.54mm_Vertical
J15: Analog Out 2; Molex_KK-254_AE-6410-03A_1x03_P2.54mm_Vertical
J16: Analog Out 3; Molex_KK-254_AE-6410-03A_1x03_P2.54mm_Vertical
J17: Analog Out 4; Molex_KK-254_AE-6410-03A_1x03_P2.54mm_Vertical
J18: Analog Out 5; Molex_KK-254_AE-6410-03A_1x03_P2.54mm_Vertical
J19: Analog Out 6; Molex_KK-254_AE-6410-03A_1x03_P2.54mm_Vertical
J20: Analog Out 7; Molex_KK-254_AE-6410-03A_1x03_P2.54mm_Vertical
J45: Conn_01x05_Pin; Molex_KK-254_AE-6410-05A_1x05_P2.54mm_Vertical
R1, R2, R3, R4, R5: 82; R_0805_2012Metric_Pad1.20x1.40mm_HandSolder
R6, R7: 4,7k; R_0805_2012Metric_Pad1.20x1.40mm_HandSolder
R8, R9, R10: 10k; R_0805_2012Metric_Pad1.20x1.40mm_HandSolder
SW1: SW_Push; SW_Push_1P1T_NO_6x6mm_H9.5mm
U1: Pico; RPi_Pico_SMD_TH
U2: MCP3208; SOIC-16_3.9x9.9mm_P1.27mm
U3: 24LC64; SOIC-8_3.9x4.9mm_P1.27mm

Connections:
+5V: C1.1, J2.3, J6.1, J8.1, U1.39 (VSYS)
/A0: J13.3, U2.1 (CH0)
/A1: J14.3, U2.2 (CH1)
/A2: J15.3, U2.3 (CH2)
/A3: J16.3, U2.4 (CH3)
/A4: J17.3, U2.5 (CH4)
/A5: J18.3, U2.6 (CH5)
/A6: J19.3, U2.7 (CH6)
/A7: J20.3, U2.8 (CH7)
/AD-CS: U1.19 (GPIO14), U2.10 (~CS/SHDN)
/Column 0: U1.20 (GPIO15); also elsewhere on the board
/Column 1: U1.12 (GPIO9); also elsewhere on the board
/Column 2: U1.26 (GPIO20); also elsewhere on the board
/DEMUX-E: U1.25 (GPIO19); also elsewhere on the board
/DEMUX-S0: U1.21 (GPIO16); also elsewhere on the board
/DEMUX-S1: U1.22 (GPIO17); also elsewhere on the board
/DEMUX-S2: U1.24 (GPIO18); also elsewhere on the board
/ENCODER-BUTTON: J45.1, R10.1, U1.11 (GPIO8)
/ENCODER-DT: J45.3, R8.2, U1.10 (GPIO7)
/LED 0: D4.2 (A), U1.4 (GPIO2)
/LED 1: D5.2 (A), U1.5 (GPIO3)
/RESET-Switch: SW1.1, U1.30 (RUN)
/SCL: J2.1, J3.4, R7.1, U1.7 (GPIO5), U3.6 (SCL)
/SDA: J2.2, J3.3, R6.1, U1.6 (GPIO4), U3.5 (SDA)
/SPI-CLK: J4.3, U1.14 (GPIO10), U2.13 (CLK)
/SPI-MISO: J4.5, U1.16 (GPIO12), U2.12 (Dout)
/SPI-MOSI: J4.4, U1.15 (GPIO11), U2.11 (Din)
/SPI-OUT-CS: J4.6, U1.17 (GPIO13)
/UART-RX: D3.1 (K), J1.3, U1.2 (GPIO1)
/UART-TX: D2.1 (K), J1.4, U1.1 (GPIO0)
unnamed: D1.2 (A), R1.1
unnamed: D2.2 (A), R2.1
unnamed: D3.2 (A), R3.1
unnamed: D4.1 (K), R4.1
unnamed: D5.1 (K), R5.1
unnamed: J5.1, U1.34 (GPIO28_ADC2)
unnamed: J5.2, U1.32 (GPIO27_ADC1)
unnamed: J5.3, U1.31 (GPIO26_ADC0)
unnamed: J5.4, U1.29 (GPIO22)
unnamed: J5.5, U1.27 (GPIO21)
VCC: C2.1, C4.1, C5.1, J1.2, J3.2, J4.2, J7.1, J10.1, J13.1, J14.1, J15.1, J16.1, J17.1, J18.1, J19.1, J20.1, R1.2, R2.2, R3.2, R6.2, R7.2, R8.1, R9.1, R10.2, U1.36 (3V3), U2.15 (Vref), U2.16 (Vdd), U3.8 (VCC); also elsewhere on the board

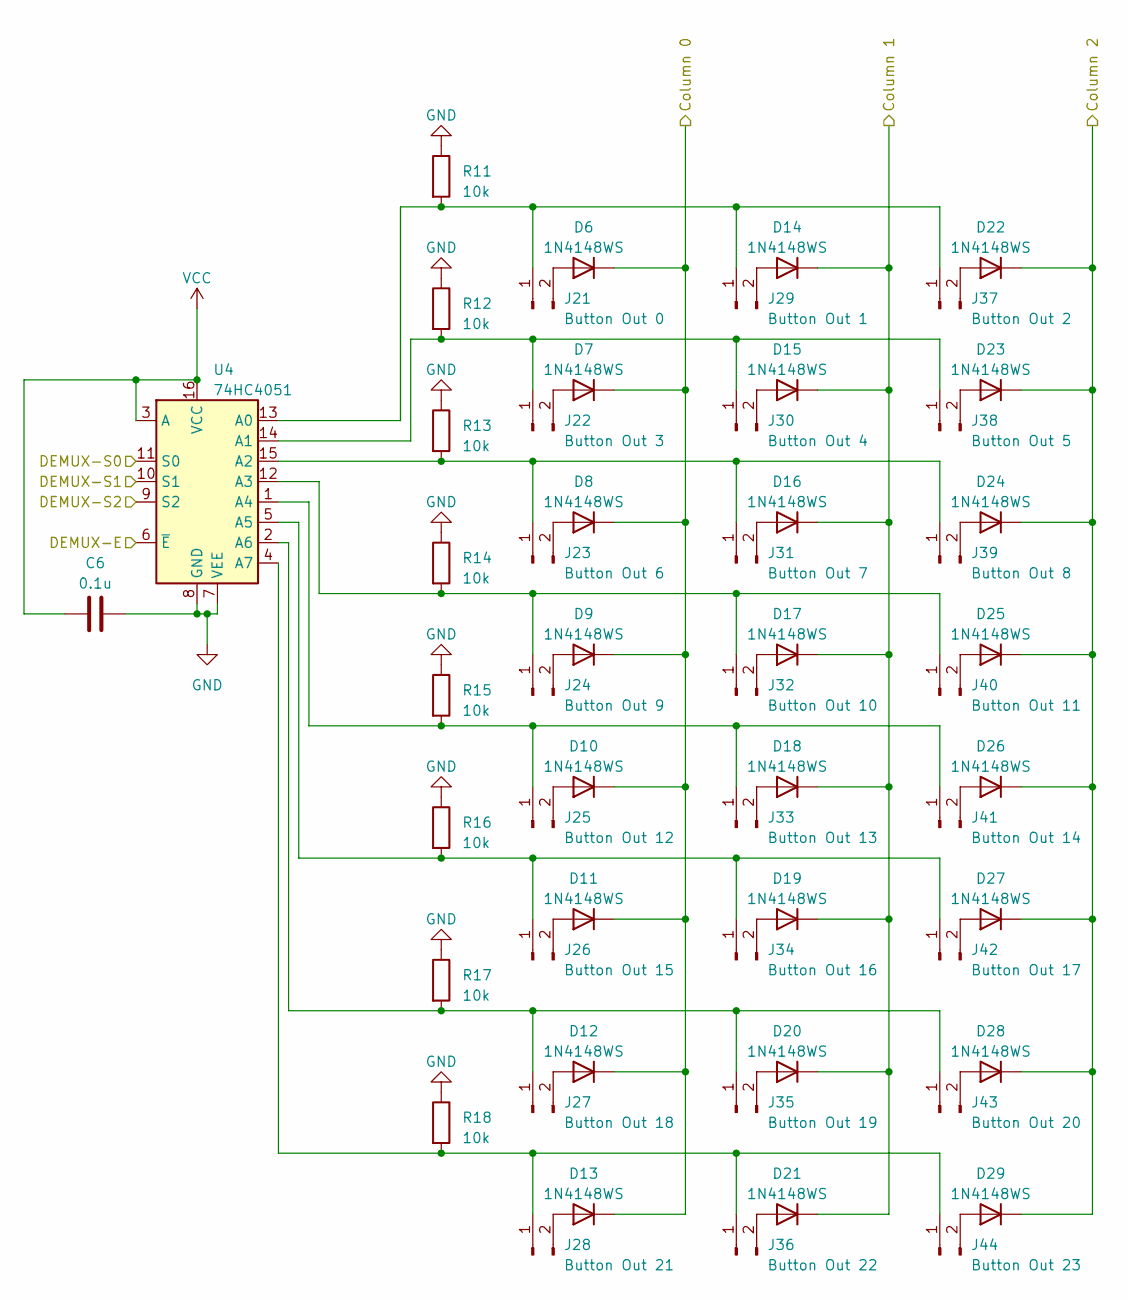
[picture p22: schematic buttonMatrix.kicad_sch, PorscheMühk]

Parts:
C6: 0.1u; C_0805_2012Metric_Pad1.18x1.45mm_HandSolder
D6, D7, D8, D9, D10, D11, D12, D13, D14, D15, D16, D17, D18, D19, D20, D21, D22, D23, D24, D25, D26, D27, D28, D29: 1N4148WS; D_SOD-323_HandSoldering
J21: Button Out 0; Molex_KK-254_AE-6410-02A_1x02_P2.54mm_Vertical
J22: Button Out 3; Molex_KK-254_AE-6410-02A_1x02_P2.54mm_Vertical
J23: Button Out 6; Molex_KK-254_AE-6410-02A_1x02_P2.54mm_Vertical
J24: Button Out 9; Molex_KK-254_AE-6410-02A_1x02_P2.54mm_Vertical
J25: Button Out 12; Molex_KK-254_AE-6410-02A_1x02_P2.54mm_Vertical
J26: Button Out 15; Molex_KK-254_AE-6410-02A_1x02_P2.54mm_Vertical
J27: Button Out 18; Molex_KK-254_AE-6410-02A_1x02_P2.54mm_Vertical
J28: Button Out 21; Molex_KK-254_AE-6410-02A_1x02_P2.54mm_Vertical
J29: Button Out 1; Molex_KK-254_AE-6410-02A_1x02_P2.54mm_Vertical
J30: Button Out 4; Molex_KK-254_AE-6410-02A_1x02_P2.54mm_Vertical
J31: Button Out 7; Molex_KK-254_AE-6410-02A_1x02_P2.54mm_Vertical
J32: Button Out 10; Molex_KK-254_AE-6410-02A_1x02_P2.54mm_Vertical
J33: Button Out 13; Molex_KK-254_AE-6410-02A_1x02_P2.54mm_Vertical
J34: Button Out 16; Molex_KK-254_AE-6410-02A_1x02_P2.54mm_Vertical
J35: Button Out 19; Molex_KK-254_AE-6410-02A_1x02_P2.54mm_Vertical
J36: Button Out 22; Molex_KK-254_AE-6410-02A_1x02_P2.54mm_Vertical
J37: Button Out 2; Molex_KK-254_AE-6410-02A_1x02_P2.54mm_Vertical
J38: Button Out 5; Molex_KK-254_AE-6410-02A_1x02_P2.54mm_Vertical
J39: Button Out 8; Molex_KK-254_AE-6410-02A_1x02_P2.54mm_Vertical
J40: Button Out 11; Molex_KK-254_AE-6410-02A_1x02_P2.54mm_Vertical
J41: Button Out 14; Molex_KK-254_AE-6410-02A_1x02_P2.54mm_Vertical
J42: Button Out 17; Molex_KK-254_AE-6410-02A_1x02_P2.54mm_Vertical
J43: Button Out 20; Molex_KK-254_AE-6410-02A_1x02_P2.54mm_Vertical
J44: Button Out 23; Molex_KK-254_AE-6410-02A_1x02_P2.54mm_Vertical
R11, R12, R13, R14, R15, R16, R17, R18: 10k; R_0805_2012Metric_Pad1.20x1.40mm_HandSolder
U4: 74HC4051; SO-16_3.9x9.9mm_P1.27mm

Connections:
/Column 0: D6.1 (K), D7.1 (K), D8.1 (K), D9.1 (K), D10.1 (K), D11.1 (K), D12.1 (K), D13.1 (K); also elsewhere on the board
/Column 1: D14.1 (K), D15.1 (K), D16.1 (K), D17.1 (K), D18.1 (K), D19.1 (K), D20.1 (K), D21.1 (K); also elsewhere on the board
/Column 2: D22.1 (K), D23.1 (K), D24.1 (K), D25.1 (K), D26.1 (K), D27.1 (K), D28.1 (K), D29.1 (K); also elsewhere on the board
/DEMUX-E: U4.6 (~E); also elsewhere on the board
/DEMUX-S0: U4.11 (S0); also elsewhere on the board
/DEMUX-S1: U4.10 (S1); also elsewhere on the board
/DEMUX-S2: U4.9 (S2); also elsewhere on the board
unnamed: D6.2 (A), J21.2
unnamed: D7.2 (A), J22.2
unnamed: D8.2 (A), J23.2
unnamed: D9.2 (A), J24.2
unnamed: D10.2 (A), J25.2
unnamed: D11.2 (A), J26.2
unnamed: D12.2 (A), J27.2
unnamed: D13.2 (A), J28.2
unnamed: D14.2 (A), J29.2
unnamed: D15.2 (A), J30.2
unnamed: D16.2 (A), J31.2
unnamed: D17.2 (A), J32.2
unnamed: D18.2 (A), J33.2
unnamed: D19.2 (A), J34.2
unnamed: D20.2 (A), J35.2
unnamed: D21.2 (A), J36.2
unnamed: D22.2 (A), J37.2
unnamed: D23.2 (A), J38.2
unnamed: D24.2 (A), J39.2
unnamed: D25.2 (A), J40.2
unnamed: D26.2 (A), J41.2
unnamed: D27.2 (A), J42.2
unnamed: D28.2 (A), J43.2
unnamed: D29.2 (A), J44.2
unnamed: J21.1, J29.1, J37.1, R11.2, U4.13 (A0)
unnamed: J22.1, J30.1, J38.1, R12.2, U4.14 (A1)
unnamed: J23.1, J31.1, J39.1, R13.2, U4.15 (A2)
unnamed: J24.1, J32.1, J40.1, R14.2, U4.12 (A3)
unnamed: J25.1, J33.1, J41.1, R15.2, U4.1 (A4)
unnamed: J26.1, J34.1, J42.1, R16.2, U4.5 (A5)
unnamed: J27.1, J35.1, J43.1, R17.2, U4.2 (A6)
unnamed: J28.1, J36.1, J44.1, R18.2, U4.4 (A7)
VCC: C6.1, U4.3 (A), U4.16 (VCC); also elsewhere on the board

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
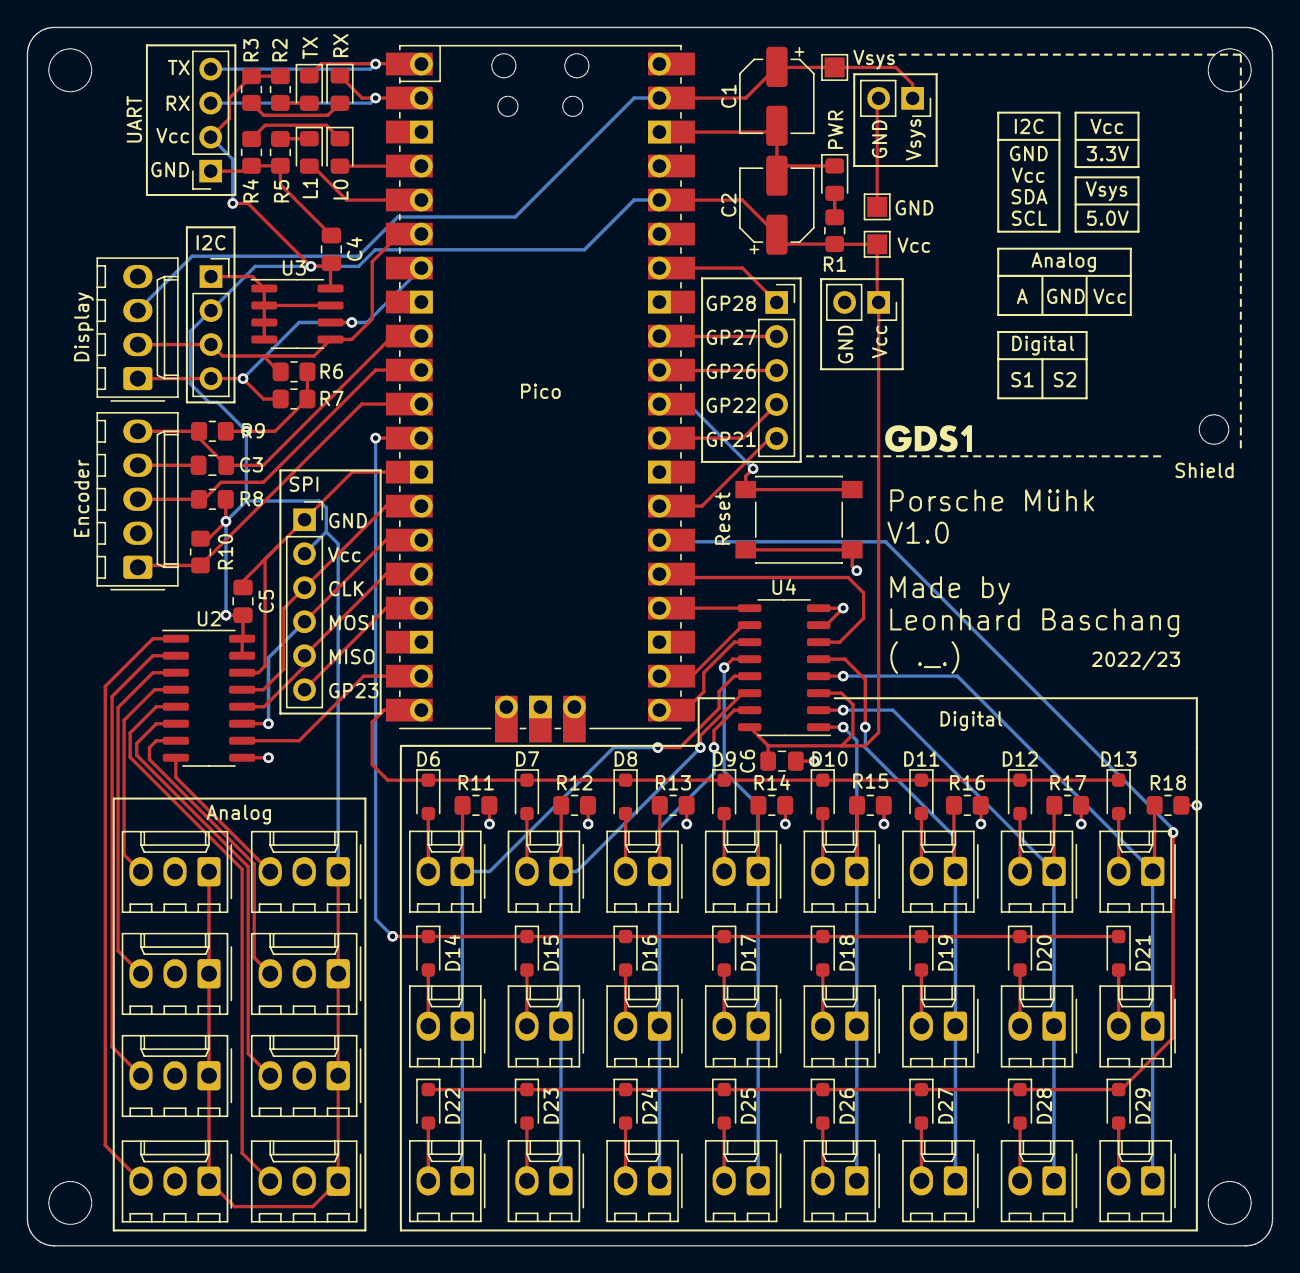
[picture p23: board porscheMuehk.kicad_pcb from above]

Board: 2 copper layers, 93.0 x 91.0 mm, 101 parts (0 on the bottom side), 75 nets.

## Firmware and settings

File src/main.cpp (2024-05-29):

// Copyright (c) 2023. Leonhard Baschang
#include <Arduino.h>
#include "LCDInput/Display.h"
#include "LCDInput/Navigator.h"
#include "LCDInput/Encoder.h"
#include "MyJoystick.h"
#include "EEPROM_Microchip_24.h"
#include "MCP3204_MCP3208.h"
#include "header.h"
#include "LiquidCrystal_I2C.h"


uint8_t buttonDemuxPins[] = {BUTTON_DEMUX_E, BUTTON_DEMUX_S0, BUTTON_DEMUX_S1, BUTTON_DEMUX_S2};
uint8_t buttonColumnPins[] = {BUTTON_COLUMN_0, BUTTON_COLUMN_1, BUTTON_COLUMN_2};


EEPROM_Microchip_24 eeprom(EEPROM_ADDRESS, EEPROM_MAX_MEMORY_ADDRESS, EEPROM_SDA_PIN, EEPROM_SCL_PIN);

MCP3204_MCP3208 adc(AD_CHANNEL_COUNT, AD_SPI_CS, AD_SPI_SCK, AD_SPI_MOSI, AD_SPI_MISO);

Display display(0x27, LCD_WIDTH, LCD_HEIGHT);

MyJoystick joystick(&adc, &eeprom, buttonDemuxPins, buttonColumnPins);

Navigator navigator(&display, &joystick);


uint32_t lastMillis;

void encoderISR() {


    if (digitalRead(ENCODER_DT_PIN)) {
        navigator.encoder->setEncoderFlag(-1);

    } else {
        navigator.encoder->setEncoderFlag(1);

    }


}

Encoder encoder(ENCODER_CLK_PIN, ENCODER_DT_PIN, ENCODER_BUTTON_PIN, &encoderISR);


void setup() {

    Serial1.begin(115200);


    pinMode(25, OUTPUT);


    Serial1.println("---------------------------------------");
    Serial1.println("---------------------------------------");
    Serial1.println("---------------------------------------");
    Serial1.println("Porsche Muehk V" + String(VERSION));
    Serial1.println("Made by Leonhard Baschang ( ._.)");
    Serial1.println("J1.2 2022/23");
    Serial1.println("J2.2 2023/24");
    Serial1.println("Made for GDS1");
    Serial1.println("---------------------------------------");


    display.init();
    navigator.init(&encoder);
    joystick.begin();

    lastMillis = 0;


}


void loop() {

    if(millis()-lastMillis >HID_UPDATE_INTERVAL){
        lastMillis = millis();
        joystick.updateAxis();
        joystick.updateButton();

    }

    navigator.checkEncoderFlag();

    navigator.encoder->checkButton();
    navigator.checkEncoderButtonFlag();
    navigator.checkDisplay();





}

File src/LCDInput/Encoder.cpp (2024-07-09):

// Copyright (c) 2023. Leonhard Baschang

#include "Arduino.h"
#include "Encoder.h"

Encoder::Encoder(uint8_t clkPin, uint8_t dtPin, uint8_t buttonPin, void (*isr)()) {
    pinMode(clkPin, INPUT);
    pinMode(dtPin, INPUT);
    pinMode(buttonPin, INPUT);
    this->buttonPin = buttonPin;

    attachInterrupt(digitalPinToInterrupt(clkPin), isr, FALLING);

    lastButtonPress = 0;


}

void Encoder::setEncoderFlag(int8_t direction) {
    flag = direction;
}

void Encoder::resetEncoderFlag() {
    flag = 0;
}

void Encoder::setButtonFlag() {
    if(millis()-lastButtonPress > 50){
        lastButtonPress = millis();
        buttonFlag = true;
    }

}

bool Encoder::readButton() const {
    return digitalRead(buttonPin);
}

void Encoder::checkButton() {
    uint8_t buttonState = readButton();
    if (buttonState && !previousButtonState) {
        previousButtonState = true;
        setButtonFlag();
    } else if (!buttonState && previousButtonState) {
        previousButtonState = false;
    }

}

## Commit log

2023-09-30 added README and fixed some bugs. Removed Libs and added them to .ini file
    [Input.cpp]
2023-12-06 changed direction of encoder
2023-12-09 fixed issue where device reinit even if it shouldn't
    [Input.cpp, Navigator.cpp]
2023-12-10 other (better) expo and log mode. Also fixed bugs with lin, expo and log modes on axes
    [Axis.cpp, Input.cpp, header.h]
2023-12-10 fixed lcd auto backlight off
    [Navigator.cpp]
2024-05-29 Changed some things. Added more hardware details
    [buttonMatrix.kicad_sch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]
2024-07-09 Fixed Output LCD line
    [Navigator.cpp]
2024-07-09 encoder button debounce
